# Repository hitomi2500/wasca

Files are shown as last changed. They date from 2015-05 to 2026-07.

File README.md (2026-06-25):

# wasca
wasca is a multipurpose Sega Saturn cartridge based on Lattice ECP5 FPGA with PicoRV32 RISC-V soft CPU core ([`picorv32`][2]). 

wasca can operate in several modes:

- Backup memory cartridge
- RAM expansion cartridge
- ROM cartridge
- Homebrew software compiled as a cartridge ROM 

> Netlink support is planned via an ESP32-CAM module connected to the 6-pin expansion header.

> Optical drive emulation (ODE) function is theoretically possible, but not planned currently.

> Profiling can be supported using a special firmware version, but it requires support from SH-2 code.

---

# Quick Start

1. Prepare the SD card formatted as FAT32. Other filesystems like NTFS and exFAT are not supported.
2. Copy `wasca.ss` and `wasca.rv` to the SD card root directory. Note that the file names should be in lowercase on the card, check FAT32 LFN support or reformat the card if they are not.
3. Insert the SD card into wasca, plug wasca into the cartridge slot, power on the console
4. Verify that the front LED on the cartridge turns red, then blue.
5. wasca menu should appear on screen after boot logo. Some ODEs can bypass wasca boot process entirely. In this case, consult your ODE documentation to learn how to return to cartridge boot mode after selecting a game.

---

# LED Status Reference

| Color | Meaning |
|---|---|
| Red | Reading SD card at startup or system error. |
| Red, blinking | Boot error, either `wasca.ss` and `wasca.rv` was not found on SD card, refer to on-screen error message. |
| Blue | Firmware found on SD card, boot successful, waiting for menu selection. |
| Green, blinking | Write access in RAM or Homebrew mode. |
| Magenta, blinking | Write access to backup memory in backup mode or filesystem write access. |
| Cyan, blinking | Massive write access to backup memory (happens during format) or filesystem read access. |
| Yellow, blinking | Preparing backup memory |
| White, blinking | Filesystem open, close, seek etc.|

---

# Backup Memory Support

wasca supports four backup memory sizes:

- 0.5 MB (official Sega Saturn size)
- 1 MB
- 2 MB
- 4 MB

If not already present, the following backup files are created automatically on the SD card when selected from the menu:

- `backup05.bin`
- `backup1.bin`
- `backup2.bin`
- `backup4.bin`

Syncronization is done automatically, led blinking with magenta color signals write access, led blinking with cyan signals massive write access and usually happens during cart format in BIOS.

---

# RAM Expansion Support

wasca supports these RAM expansion modes:

- 1 MB official RAM expansion (timings not 100% compatible)
- 4 MB official RAM expansion
- Heart of Darkness mode (HoD will work in homebrew mode as well)

---

# ROM Support

The following games require corresponding ROM files placed in the SD card root directory:

| Game | Required File |
|---|---|
| King of Fighters '95 | `kof95.bin` |
| Ultraman | `ultraman.bin` |

When present on SD card, ROM will appear in menu and should be selected prior to launching the game.

---

# Homebrew Support

Any Sega Saturn homebrew compiled for cartridge can be placed into the SD card root directory. `.ss` and `.bin` extensions are supported. wasca automatically scans and lists `.bin` and `.ss` files found in the SD card root directory.

In homebrew mode, wasca exposes:

- 32 MB of CS0 space
- 16 MB of CS1 space

These regions are available to the developer as RAM.

[`Yaul`][1] system library supports compiling sortware for cartridge with a special makefile include (build.post.ss.mk) that should be added to the project's Makefile instead of the default one (build.post.iso-cue.mk).

---

# Menu limit

Currently, wasca menu is limited to 18 items. If more `.bin` and `.ss` files that fit on screen are present in the SD card root, only first items will be shown. Use wasca commander (still under development) file manager to load extra files or files in non-root folders.

---

# Firmware update

wasca firmware consists of 3 parts:

- FPGA gateware: `attosoc.bit`
- RISC-V firmware: `wasca.rv`
- SH-2 firmware: `wasca.ss`

### Updating FPGA gateware

1. Disconnect wasca from the console
2. Remove two screws on the back of the cartridge
3. Open the cartridge shell
4. Connect wasca to PC using USB-C cable
5. A removable drive will appear
6. Copy `attosoc.bit` onto the drive
7. Wait for 2 minutes before disconnecting the cartridge
8. Assemble the cartridge and connect to the console.

### Updating RISC-V and SH-2 Firmware

1. Remove SD card from wasca
2. Replace the existing `wasca.rv` and `wasca.ss` files on the SD card with a newer version.
3. Re-insert the card. Console power cycle is necessary for wasca to load the new firmware.

---

# SD card removal
Removing the SD card when console is powered up is only recommended when the front LED is not lit and not blinking. Re-inserting the card without reset is possible if LED did not blink while the card was removed, but data integrity is not tested and not guaranteed.

---

# Troubleshooting

### Lit red LED and/or "wasca : boot error" on screen

Possible causes:
- Unsupported filesystem
- Bad SD card
- Unstable SD card connection

Try:
- Re-insert the SD card
- Reformat the SD card as FAT32
- Replace SD card

### Blinking red LED and/or missing file message on screen

Possible causes:
- Missing `wasca.ss` or `wasca.rv` in the SD card root
- Unsupported filesystem
- Bad SD card

Try:
- Verify that both `wasca.ss` and `wasca.rv` exists in the SD card root directory, named in lowercase
- Reformat the SD card as FAT32
- Replace the SD card

### Lit blue LED, wasca boot menu does not appear during boot

Possible causes:
- Poor cartridge connection
- Dirty cartridge connector
- ODE bypassing cartridge initialization

Try:
- Reseating the cartridge
- Cleaning the cartridge and connector
- Consulting your ODE documentation for cartridge boot instructions

### Game ROM of homebrew .ss file present in root folder, but does not appear in the menu

Possible causes:
- Too many files in SD card root
- Wrong charset

Try:
- Verify that there is enough place on the screen to print necessary menu item. If last menu item is 18, it's probably overfilled and extra items are not shown.
- Verify that the file extension is `.bin` or `.ss`, lowercase, latin1 characters.

[1]: https://github.com/ijacquez/libyaul
[2]: https://github.com/YosysHQ/picorv32

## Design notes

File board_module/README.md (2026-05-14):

This version of wasca board uses Muselab's Icesugar-pro board as a submodule.

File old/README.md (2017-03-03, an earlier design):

# wasca
Sega Saturn multipurpose cartridge, still in development phase. It will mimic Power Memory / Backup RAM, 1MB ROMs from KoF and Ultraman, and 1M/4M RAM expansion. More than that, it should emulate Sega Saturn modems, and launch any 3rd party code, for example PseudoSaturn.
Cart is based on Altera MAX 10 FPGA with external SDRAM and internal Nios II soft CPU. 
Development version is built around Zynq-based board named snickerdoodle.




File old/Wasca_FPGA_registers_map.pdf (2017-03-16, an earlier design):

## Wasca memory maps v. 0.4

This is a short document describing max10-based wasca cartridge memory and registers map from both SH-2 and in-FPGA Nios II soft cpu perspective. It also covers some aspects about developer Zynq-based board (this one is not named yet).
Part 1. SH-2 memory map
All the absolute addresses in this part of the document are in SH-2 cache-through address space unless otherwise specified.
Table 1-1 describes differencies between SH-2's chipselect spaces and A-bus (SMPC's chipselects). Further chipselect references will be using A-Bus ranges.
Address range | Size | SH-2 chipselects | A-Bus Chipselects | wasca usage
0x22000000 -0x23FFFFFF | 32 MB | CS0 | CS0 | Yes
0x24000000 -0x24FFFFFF | 16 MB | CS1 | CS1 | Yes
0x25000000 -0x257FFFFF | 8 MB | | Dummy | No
0x25800000 -0x258FFFFF | 1 MB | | CS2 | Not yet

Table 1-1. SH-2 and A-bus chipselect ranges.

Table 1-2 shows a detailed map of CS0 and CS1 and its usage by some official and unofficial carts.

Address range | Size | CS | Power memory | RAM cart | ROM cart | Bootable cart
0x22000000 - 0x221FFFFF | 2 M | CS0 | | | Data | Code and data
0x22200000 - 0x223FFFFF | 2 M
0x22400000 - 0x225FFFFF | 2 M | | | Lower data
0x22600000 - 0x227FFFFF | 2 M | | | Upper data
0x22800000 - 0x23FFFFFF | 24 M
0x24000000 – 0x24FEFFFF | 15.9999 M | CS1 | Data
0x24FFFFFC | 4 | | ID | ID | 0xFFFF | 0xFFFF

Table 1-2. Detailed CS0 and CS1 memory maps for various carts.

Table 1-3 shows the same map of CS0 and CS1 and its usage by wasca. Empty areas in tables 1-2 and 1-3 are unmapped, and should return unpredictable value (mostly 0xFFFF) on every read access. Write accesses in these areas are ignored.

Address range | Size | CS | wasca mode
| | | INIT | Power memory | RAM | <32M ROM | 32M ROM
x22000000 - 0x221FFFFF | 2 M | CS0 | Bootcode | | | ROM | ROM
0x22000000 - 0x223FFFFF | 2 M
0x22400000 - 0x225FFFFF | 2 M | | | | RAM
0x22600000 - 0x227FFFFF | 2 M
0x22800000 - 0x23FEFFFF | 23.94 M
0x23FF0000 - 0x23FFDFFF | 56K | | Reserved
0x23FFE000 - 0x23FFEFFF | 4K | | Filesystem interface
0x23FFF000 - 0x23FFFFFF | 4K | | wasca system area
0x24000000 - 0x24FE0FFF | 15.94 M | CS1 | | Power memory
0x24FF0000 - 0x24FFDFFF | 56K | | | | | | Reserved
0x24FFE000 - 0x24FFEFFF | 4K | | | | | | File system interface
0x24FFF000 - 0x24FFFFFB | 4092 | | | | | | wasca system area
0x24FFFFFC (ID) | 4 | | 0xFF | 0x2x | 0x5x | 0xFF | 0xFF
Table 1-3. Detailed CS0 and CS1 memory maps.

Filesystem interface is introduced to allow SH2 browse SD card or other media content, read, write or select files there. Selecting file is required for custom ROM operation mode. Filesystems registers are 16-bit-wide and should be accessed with 16-bit accesses and 16-bit address align. Other access sizes and/or unaligned addresses will lead to unpredictable behavior. Filesystem is locked after reset, and should be unlocked by writing 0xFADE inlo LOCK register. While locked, filesystem interface behaves as an unmapped area, LOCK register is write-only.

Offset | Size | R/W | Name | Description
0x000 | 2048 | R/W | DATA BUFFER | Buffer for storing data for write and read operations.
0x800 | 2032 | R/W | COMMAND BUFFER | Buffer for storing commands and replies. SH-2 software should write a valid command here before writing to bit 0 of the COMMAND register. Commands should be UTF8-encoded. When bit 0 in STATUS register reports a command completion, SH-2 should expect result here. Error messages requested by bit 1 in the command register appears here as well. SH-2 should not read this buffer while busy bit in STATUS register is active.
0xFF0 | 2 | R/W | LOCK | Write 0xFADE to this register to unlock filesystem functionality. Filesystem control is locked after every reset

| | | | and should be unlocked by SH2 software. Writing any other value into this register enables lock again.
0xFF2 | 1 | W | COMMAND | SH-2 software should write '1' to bit 0 to start a command stored in the command buffer beforehand. To get last error message, SH-2 software should write '1' to bit 1. Other bits are reserved, and should be written as zeros.
0xFF4 | 2 | R | STATUS | Bit 0 : busy bit, 1 when command is processed, 0 when done. Bit 1 : error bit, flags if any errors were detected during the last command. Other bits are reserved and should be ignored.

Table 1-4. Filesystem interface.

Filesystem interface support a reduced set of unix-shell-like commands. Please note that the command syntax and replies structure are not unix-shell compatible, do not use a man pages or other general documentation as a reference. Supported commands are enclosed in table 1-5. <0> are zero-terminators.
File and folder names could be either relative (e.g. “sound/sega.wav”), or absolute (e.g. “/sdcard/media/sound/sega.wav”). If no path provided for a filename, current folder is used.
Command | Syntax | Description
cd | cd <folder><0> | Enters a specified folder. If “..” is provided as a folder name, leaves current folder.
close | close <0> | Closes currently opened file.
cp | cp <filename 1> <filename 2><0> | Copies file1 to file2. If file2 exists, returns error and does nothing.
ls | ls<0> | Lists current folder. Filename are is stored in the COMMAND BUFFER, separated by zero-symbols. List is ended by double zero. Due to limited command buffer size, command could return an incomplete list, to get further files in the folder SH-2 software should issue ls command again. When the command returns a zero list (started by a two zero-symbols), there are no more files to list. Issuing any other command resets this one to the start of the folder.
mv | mv <filename 1> <filename 2><0> | Moves file1 to file2. If file2 exists, returns error and does nothing.
open | open <filename> [ <access>]<0> | Opens a file for reading or writing. Valid access fields are “r” (read-only, default), “w” (read-write), “n” (read-write, create file, truncate file if exists). If the file does not exist and the access field is not “n”, error is returned. Only 1 file can be opened at a time, issuing open when a file is already open closes currently open file.
pwd | pwd<0> | Returns current path
read | read <number><0> | Reads a number of bytes into DATA BUFFER. Returns error if number is more than 2048 or no file is currently opened.
rm | rm <filename><0> | Deletes a file from the filesystem. If file does not exist, returns error.
seek | seek <number><0> | Sets a data pointer in a file to the position provided by

| | number. Poiter is automatically set to 0 when opening file, and auto-increases when reading or writing, so seeking could be avoided when accessing file from the start to the end.
stat | stat <filename><0> | Returns a detailed file characteristics, like size, permissions, user, group etc. in the text format similar to 'ls -l' in linux.
write | write <number><0> | Writes a number of bytes from DATA BUFFER. Returns error if number is more than 2048 or no file is currently opened.

Table 1-5. Filesystem commands.

Table 1-6 describes wasca system area. System wasca registers are 16-bit-wide and should be accessed with 16-bit accesses and 16-bit address align. Other access sizes and/or unaligned addresses will lead to unpredictable behavior. Address range for system area is remapped in 32M ROM mode.

Offset | Size | R/W | Name | Description
0x000 | 4080 | | Reserved
0xFF0 | 2 | R | PCNTR | Wasca Prepare counter. Reset value is 0, after writing a valid value to MODE, this counter shows value (in percents) of the prepare progress. When this register has value of 0x0064, wasca is ready to emulate specified cart. Higher values should not appear normally.
0xFF2 | 2 | R | STATUS | Wasca Status register. Error and flag bits appears here. Bit 0 – SD card error when 1 Bit 1 – SDRAM test failed when 1 Bit 2 – USB transfer error when 1 Other bits are reserved
0xFF4 | 2 | R/W | MODE | wasca Mode Register Divided into 4 octets, non-zero octet selects cart type, octet value selects card subtype. See table 5 for additional description. Setting values not provided in table 5 results in unpredictable behavior.
0xFF6 | 2 | R | HWVER | wasca hardware version, major and minor 0x050C = v5.12
0xFF8 | 2 | R | SWVER | wasca embedded software version, major and minor (same format as HWVER) This register is zero at reset, and is written by cart's firmware right after boot. If by the time SH-2 is running the bootcode this value is still zero, it means cart failure. SH-2 cannot alter this register.
0xFFA | 6 | R | SIGNATURE | For max10 “wasca “ in ASCII (0x7761 0x7363 0x6120), for snickerdoodle “doodle” in ASCII (0x646F 0x6F64 0x6C5C). Signature unavailable in remapped (32M ROM) mode.

Table 1-5. Wasca system area registers.

Okay, and now the promised wasca modes table:

MODE value | Description
0x0000 | INIT
0x0001 | Power memory, 0.5 MB
0x0002 | Power memory, 1 MB
0x0003 | Power memory, 2 MB
0x0004 | Power memory, 4 MB
0x0020 | RAM expansion, 1 MB
0x0040 | RAM expansion, 4 MB
0x0100 | ROM, KoF95.bin
0x0200 | ROM, Ultraman.bin
0x0F00 | ROM, custom. Actual ROM file is selected via filesystem interface by SH-2. If the file size is 32M, wasca registers are remapped according to the table 1-3.
Other values | Unpredictable

Table 1-5. Valid wasca MODE register values.

Part 2. Nios II memory map
Nios II address range is FPGA-dependent (will be different for different FPGA parts) and is still work in progress, so it might change occasionally. Please check the last wasca FPGA project from repository for the valid memory map. Table 2-1 shows a memory map for Nios II soft cpu.
Address range | Size | Description
0x00000000 -0x0002AFFF | 172 KB | On-chip flash. It stores both Nios II software and SH-2 bootcode (compiled into Nios II software as binary).
0x00040000 — 0x0040001F | 32 B | UART registers
0x00041000 — 0x000417FF | 2 KB | Debug RAM
0x00042000 — 0x0004200F | 16 B | PLL setup
0x00043000 — 0x000433FF | 1 KB | SD card interface
0x00044000 — 0x0004400F | 16 B | Reserved
TBD | TBD | Filesystem interface
0x00045000 — 0x000451FF | 512 B | wasca system registers
0x00080000 — 0x000827FF | 10K | RAM

Table 2-1. Nios II memory map.

The scope of this document does not cover Nios II peripheral description, but it is well covered in Altera docs. The custom cores in Nios II memory map are filesystem interface and wasca system registers interface. Filesystem interface is TBD, wasca system area is shown in table 2-2.

Offset | Size | R/W | Name | Description
0x000 | 4080 | | Reserved
0xFF0 | 2 | R/W | PCNTR | Wasca Prepare counter. After sensing a non-zero value in MODE register Nios should start the prepare process, and write the progress periodically into this value (in percents).
0xFF2 | 2 | R/W | STATUS | Wasca Status register. Nios should write status here. See corresponding register in SH-2 memory map.
0xFF4 | 2 | R | MODE | wasca Mode Register Nios should scan this register while in INIT mode, and switch to corresponding mode when it changes. See corresponding register

| | | | in SH-2 memory map.
0xFF6 | 2 | R | HWVER | wasca hardware version, major and minor 0x050C = v5.12
0xFF8 | 2 | R/W | SWVER | This register is zero at reset, and is written by Nios soft CPU right after boot. See corresponding register in SH-2 memory map.
0xFFA | 6 | | Reserved

Table 2-2. wasca system area from Nios II perspective.

Part 3. Zynq memory map
Zynq memory map is generated automatically by Vivado. After this Vivado generates macros for every IP core, and the actual address is tied to that macros. Therefore, in the scope of this document, only the relative addresses (within IP core) will be described.

CORE 1: A-Bus bridge.
Accessible by AXI4Lite bus for status and configuration. Uses the same address map as Nios II (see table 2-2).

CORE 2: Filesystem interface.
Accessible by AXI4Lite bus for data transfer. Uses the same address map as Nios II (TBD).

CORE 3: Snoop core.
Accessible by AXI4Lite bus for status and configuration. Snoop core catches transactions over A-Bus and records them as a list into DDR.
Offset | Size | R/W | Name | Description
0x000 | 4 | R/W | SNOOP_ADDRESS | Selects address in an AXI space range for snooping A-BUS data transactions.
0x004 | 4 | R/W | SNOOP_FILTER | Filter for snooping only desired transactions. Set the corresponding bit to 1 to enable. Bit 0 – CS0, Bit 1 – CS1, Bit 2 – CS2, Bit 3 – reads, Bit 4 – writes.
0x008 | 4 | R/W | SNOOP_FORMAT | Snooping format as follows: 0x00 – 16 bit (1bit r/w, 15 bit lower address) 0x01 – 32 bit (1 bit r/w, 2 bit cs, 26 bit address, 3 bit hold length) 0x02 – 64 bit (1 bit r/w, 2 bit cs, 26 bit address, 16 bit data, 3 bit hold length, 1 bit hold ignore, 15 bit timestamp)
0x00C | 4 | R/W | SNOOP_CONTROL | Bit 0 enables and disables snoop. Bit 1 resets snoop to start address and clears itself.
0x010 | 4 | R | SNOOP_COUNTER | Holds value for current number of transactions snooped. Resets to 0 after setting bit 1 in SNOOP_CONTROL

CORE 4: Display core.
Accessible by AXI4Lite bus for data transfer. Display sports its own internal video buffer, so the data in the core's memory is not displayed upon writing, but should be uploaded from core into display first. To do this one should either upload data manually by writing 1 to
DISPLAY_CONTROL register, or enable auto-upload.
Offset | Size | R/W | Name | Description
0x00000 | 0x12C00 | R/W | FRAMEBUFFER | Framebuffer for holding pixel data.
0x1F000 | 1 | R/W | DISPLAY_CONTROL | Bit 0 – uploads framebuffer upon writing 1 Bit 1 – enables automatic upload

0x1F004 | 1 | R | UPLOAD_STATUS | Bit 0 – upload is active.
0x1F008 | 4 | R/W | UPLOAD_INTERVAL | Automatic upload interval in microseconds.
0x1F00C | 4 | R | UPLOAD_COUNTER | This counter cyclically counts from 0 to UPLOAD INTERVAL, then resets to 0 and starts over. Upload occurs when UPLOAD_COUNTER is 0. Upload takes some time, software should check UPLOAD_STATUS register before writing to buffer.
0x1F010 | 1 | R/W | BACKLIGHT | Backlight intensity. 0x00 – minimal, 0xFF -maximal.

Part 4. Revision history

v0.1 | Preliminary version, system regs and SD card interface, only SH-2 perspective
v0.2 | Nios perspective added, some additional comments
v0.3 | SD card interface removed, filesystem interface added, Zynq perspective added
v0.4 | Filesystem interface changed drastically

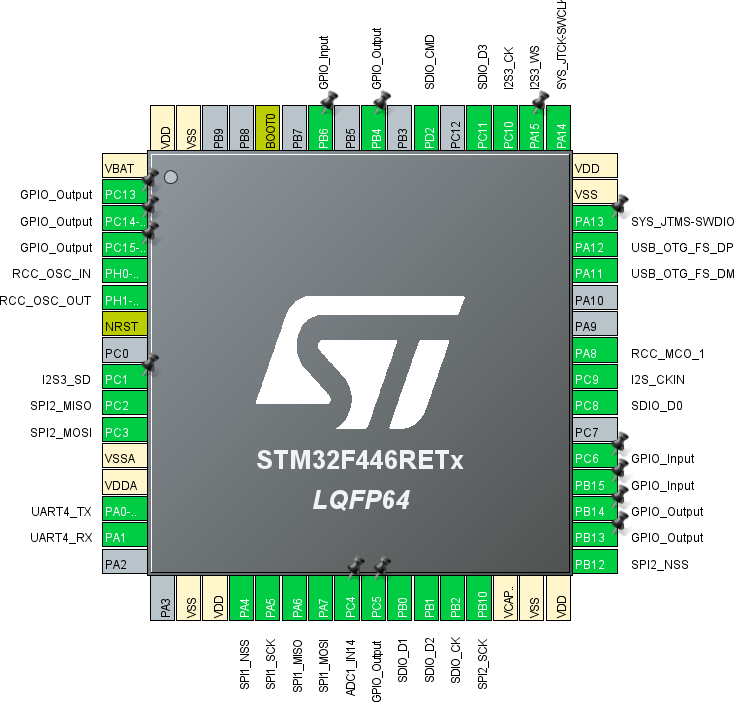
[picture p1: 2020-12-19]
board_module/STM32_pinout.png

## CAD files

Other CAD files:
fpga_firmware/wasca_signaltap.stp

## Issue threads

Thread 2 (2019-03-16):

SDRAM access timing adjustement in firmware v1.x

cafe-alpha, 2019-03-16:
Long time no see ! Pseudo Saturn Kai development reached a milestone big enough so that I can finally put more time on Wasca development.

And, as indicated in the title, I'm currently experiencing SDRAM access issues in firmware v1.x (MAX 10-based) from a design to another, which improves by randomly changing settings in Qsys and heavy prayings ... in simpler words, I'm flooded with technical difficulty of firmware development.

So I would like to know how you managed to adjust access timing for SDRAM in v1.0 board (which was running Saturn test utility from emulated boot ROM, hence with working SDRAM access) : from my limited understanding, as this requires to dedicate one clock signal for SDRAM chip (and adjust its phase with slack from address/data signals), I was thinking to use second clock output from MAX10's PLL as clock signal for SDRAM.
But firmware v1.0/v1.1 uses only one clock output from PLL, so if there's another way to adjust SDRAM access timing, please inform me about it.

I suppose you still prefer the snickerdoodle-based architecture, but that would be really appreciated if you want to give an hand on MAX 10 one ♪

hitomi2500, 2020-08-17:
Just thought about commenting on this one. I actually never fine-tuned any hard timings or pin delays, it worked magically as it was. Yes, there was some qsys config involved, but it was only about CAS latency and other timings from datasheet. Basically, it's the second page of the sdram controller setup.
As far as i understand, the sdram controller expects its clock to be the same as memory IC clock, and it does the data-to-clock phase alignement (basically just latching with a negative clock edge at the i/o) itself.

cafe-alpha, 2020-08-18:
Thank you for the reply. I honestly don't remember in detail which kind of problem I had at the moment I wrote this issue, but it was either me having troubles to read the datasheet or incorrectly soldering things on the PCB ? Or maybe it was more likely to occur when SPI component was added ?
Now, I no longer have such kind of problem, but it's also a long time I didn't tested on my own board. I can't wait to try your design on it !

hitomi2500, 2021-02-05:
I suppose i will close this one.

Closed 2021-02-05.

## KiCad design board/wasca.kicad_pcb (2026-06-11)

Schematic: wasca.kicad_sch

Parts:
C1, C2, C4, C5, C7, C9, C10, C11, C14, C15, C16, C17, C18, C19, C20, C21, C22, C23, C24, C25, C26, C27, C28, C33, C34, C35, C36, C37, C38, C39, C40, C46, C47, C48: 0.1uF; C_0603_1608Metric_Pad1.08x0.95mm_HandSolder; LCSC C1590
C3, C6, C8, C29: 4.7uF; C_0603_1608Metric_Pad1.08x0.95mm_HandSolder; LCSC C1705
C12, C13: 15pF; C_0603_1608Metric_Pad1.08x0.95mm_HandSolder; LCSC C1644
C30, C31: 22uF; C_0603_1608Metric_Pad1.08x0.95mm_HandSolder; LCSC C59461
C32, C41: 1uF; C_0603_1608Metric_Pad1.08x0.95mm_HandSolder; LCSC C1592
C42, C43: 18pF; C_0603_1608Metric_Pad1.08x0.95mm_HandSolder; LCSC C1647
C44, C45: 10uF; C_1206_3216Metric_Pad1.33x1.80mm_HandSolder; LCSC C1691
C49, C50, C51, C52, C53, C54, C55, C56, C57, C58, C59: 0.1uF; C_0402_1005Metric; LCSC C1525
CN1: UC09-0B16F00P11; DX07S016JA1R1500; LCSC C36936538
CN2: CARTRIDGE_EDGE_CONNECTOR; CARTRIDGE_EDGE_CONNECTOR2; not fitted
CN3: TFP09-2-12B; TFP09212B; Manufacturer_Part_Number TFP09-2-12B; not fitted
CN4: SD-CARD 11P; 693063020911; PART-NUMBER 693063020911; LCSC C7529393
CN5: 2.54-1*8P母环保; MODULE_ESP32-CAM-HALF; LCSC C27438
D1: BAT54C; SOT-23; LCSC C2135
D2: LED_RGB; LED_RGB_5050-6; not fitted
D3: LED_BKGR; LED_D5.0mm-4_RGB; LCSC C7371892
D4: LED; LED_0805; LCSC C965863
KICAD1: KICAD_LOGO; DESIGNED_WITH_KICAD_10X05; not fitted
L1, L2: 2.2uH; L_1008_2520Metric; LCSC C86092
R1, R4: 5.1K; R_0603_1608Metric_Pad0.98x0.95mm_HandSolder; LCSC C23186
R2, R19, R20: 1K; R_0603_1608Metric_Pad0.98x0.95mm_HandSolder; LCSC C21190
R3, R7, R8, R16, R17, R28: 0; R_0603_1608Metric_Pad0.98x0.95mm_HandSolder; LCSC C21189
R5, R6: 27; R_0603_1608Metric_Pad0.98x0.95mm_HandSolder; LCSC C25190
R9: 680K; R_0603_1608Metric_Pad0.98x0.95mm_HandSolder; LCSC C2907061
R10: 200K; R_0603_1608Metric_Pad0.98x0.95mm_HandSolder; LCSC C25811
R11, R14, R15: 470; R_0603_1608Metric_Pad0.98x0.95mm_HandSolder; LCSC C23179
R12: 150K; R_0603_1608Metric_Pad0.98x0.95mm_HandSolder; LCSC C22807
R13: 240K; R_0603_1608Metric_Pad0.98x0.95mm_HandSolder; LCSC C4197
R18, R35: 4K7; R_0603_1608Metric_Pad0.98x0.95mm_HandSolder; LCSC C23162
R21, R22, R29, R30, R31, R32, R33, R34, R36: 10K; R_0603_1608Metric_Pad0.98x0.95mm_HandSolder; LCSC C15401
R23, R24, R25, R26, R27: 33K; R_0603_1608Metric_Pad0.98x0.95mm_HandSolder; LCSC C4216
SEGATA1: LOGO; Segata_Sanshiro; not fitted
SHIRO!1: SHIRO_LOGO; SHIRO!; not fitted
SW1, SW2: TS-1101-C-W; SW_Tactile_SPST_NO_Straight_CK_PTS636Sx25SMTRLFS; LCSC C318938
TP1: TestPoint; TestPoint_Pad_D1.5mm; not fitted
TP2: 5VSAT; TestPoint_Pad_D1.5mm; not fitted
TP3: 5VSYS; TestPoint_Pad_D1.5mm; not fitted
TP4: 5VUSB; TestPoint_Pad_D1.5mm; not fitted
TP5: 2.5V; TestPoint_Pad_D1.5mm; not fitted
TP6: 3.3V; TestPoint_Pad_D1.5mm; not fitted
TP7: 1.1V; TestPoint_Pad_D1.5mm; not fitted
TP8: DONE; TestPoint_Pad_D1.0mm; not fitted
TP9: TCK; TestPoint_Pad_D1.0mm; not fitted
TP10: TDI; TestPoint_Pad_D1.0mm; not fitted
TP11: TMS; TestPoint_Pad_D1.0mm; not fitted
TP12: TDO; TestPoint_Pad_D1.0mm; not fitted
TP13, TP14: TestPoint; TestPoint_Pad_D1.0mm; not fitted
U1, U2, U4, U5, U6: SN74LVC1T45DBVR; SOT-23-6; LCSC C7843
U3, U17: P25Q16SH-SSH-IR; SOIC-8_5.3x5.3mm_P1.27mm; LCSC C7466814
U7, U8, U10: 74ALVC164245DGG:11-JSM; TSSOP-48_6.1x12.5mm_P0.5mm; LCSC C53436298
U9: RP2040; QFN-56-1EP_7x7mm_P0.4mm_EP3.2x3.2mm; LCSC C2040
U11, U12: W9825G6KH-6; TSOP-II-54_22.2x10.16mm_P0.8mm; LCSC C62246
U13, U14: SY8008CAAC; SOT23-5_SY8008B_SGY; LCSC C81889
U15: XC6206P252MR; SOT-23-3; LCSC C15906
U16: LFE5U-25F-6BG256I; caBGA256_LAT; LCSC C1521614
VACHE1: LOGO; LOGO_VACHE_SIM; not fitted
Y1: X322512MSB4SI; Crystal_SMD_3225-4Pin_3.2x2.5mm; LCSC C9002
Y2: SX2M25.000M20F30TNN; Oscillator_SMD_SeikoEpson_SG210-4Pin_2.5x2.0mm_HandSoldering; LCSC C2901601

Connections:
/5V_SATURN_DETECT: R35.2, R36.1, U16.J13 (PR17C)
/+1_1V: C54.1, C56.1, C58.1, R17.2, U16.G6 (VCC), U16.G7 (VCC), U16.G9 (VCC), U16.L8 (VCC), U16.L9 (VCC), U16.L10 (VCC)
/+1_1V_RPI: C22.1, C24.1, C26.1, TP1.1 (1_1), U9.23 (DVDD), U9.45 (VREG_VOUT), U9.50 (DVDD)
/+2_5V: C49.1, C50.1, R8.2, U16.G11 (VCCAUX), U16.L7 (VCCAUX)
/+3_3V: C4.1, C5.1, C7.1, C17.1, C18.1, C19.1, C20.1, C21.1, C23.1, C25.1, C27.1, C28.1, C33.1, C34.1, C35.1, C36.1, C37.1, C38.1, C39.1, C40.1, C46.1, C48.1, C51.1, C52.1, C53.1, C55.1, C57.1, C59.1, CN3.4 (VDD), CN4.4 (VDD), R7.2, R16.2, R19.2, R21.1, R22.1, R23.1, R24.1, R25.1, R26.1, R27.1, R28.1, R29.1, R30.1, R31.1, R32.1, R33.1, R34.1, U1.1 (VCCA), U2.1 (VCCA), U3.8 (VCC), U4.1 (VCCA), U4.5 (DIR), U5.1 (VCCA), U5.5 (DIR), U6.1 (VCCA), U6.5 (DIR), U7.31 (VCCA), U7.42 (VCCA), U8.31 (VCCA), U8.42 (VCCA), U9.1 (IOVDD), U9.10 (IOVDD), U9.22 (IOVDD), U9.33 (IOVDD), U9.42 (IOVDD), U9.44 (VREG_VIN), U9.48 (USB_VDD), U9.49 (IOVDD), U10.31 (VCCA), U10.42 (VCCA), U11.1 (VDD), U11.3 (VDDQ), U11.9 (VDDQ), U11.14 (VDD), U11.27 (VDD), U11.43 (VDDQ), U11.49 (VDDQ), U12.1 (VDD), U12.3 (VDDQ), U12.9 (VDDQ), U12.14 (VDD), U12.27 (VDD), U12.43 (VDDQ), U12.49 (VDDQ), U16.F6 (VCCIO0), U16.F7 (VCCIO0), U16.F10 (VCCIO1), U16.F11 (VCCIO1), U16.H6 (VCCIO7), U16.H7 (VCCIO7), U16.H11 (VCCIO2), U16.J6 (VCCIO6), U16.J7 (VCCIO6), U16.J11 (VCCIO2), U16.K11 (VCCIO3), U16.L6 (VCCIO8), U16.L11 (VCCIO3), U16.P10 (CFG_1), U17.8 (VCC), Y2.4 (Vcc)
/+5V_SATURN: C1.1, C2.1, C3.1, C8.1, C9.1, C10.1, C11.1, C14.1, C15.1, C16.1, CN2.A1 (VCC), CN2.A2 (VCC), CN2.A27 (VCC), CN2.A67 (VCC), CN2.B1 (VCC), CN2.B2 (VCC), CN2.B27 (VCC), CN2.B67 (VCC), D1.1, R35.1, TP2.1 (1_1), U1.6 (VCCB), U2.6 (VCCB), U4.6 (VCCB), U5.6 (VCCB), U6.6 (VCCB), U7.7 (VCCB), U7.18 (VCCB), U8.7 (VCCB), U8.18 (VCCB), U10.7 (VCCB), U10.18 (VCCB)
/+5V_SYS: C29.1, C30.1, C31.1, C32.1, C47.1, CN5.1 (5V), D1.3, TP3.1 (1_1), U13.1 (EN), U13.4 (IN), U14.1 (EN), U14.4 (IN), U15.3 (VI)
/+5V_USB: C6.1, CN1.A4 (VBUS), CN1.A9 (VBUS), CN1.B4 (VBUS), CN1.B9 (VBUS), D1.2, TP4.1 (1_1)
/ABUS_3V_A1: U10.43 (1A3), U16.J14 (PR20C)
/ABUS_3V_A2: U7.30 (2A4), U16.T6 (PB4A)
/ABUS_3V_A3: U7.32 (2A3), U16.P5 (PL47D)
/ABUS_3V_A4: U7.33 (2A2), U16.R5 (PL44A)
/ABUS_3V_A5: U7.35 (2A1), U16.T4 (PL44B)
/ABUS_3V_A6: U7.36 (2A0), U16.R4 (PL41C)
/ABUS_3V_A7: U7.37 (1A7), U16.T3 (PL41D)
/ABUS_3V_A8: U10.37 (1A7), U16.N13 (PR38A)
/ABUS_3V_A9: U10.38 (1A6), U16.L13 (PR29C)
/ABUS_3V_A10: U10.41 (1A4), U16.K14 (PR20D)
/ABUS_3V_A11: U10.40 (1A5), U16.L14 (PR32C)
/ABUS_3V_A12: U10.35 (2A1), U16.P11 (PR47C)
/ABUS_3V_A13: U10.36 (2A0), U16.N12 (PR44D)
/ABUS_3V_A14: U7.38 (1A6), U16.R3 (PL41B)
/ABUS_3V_A15: U10.33 (2A2), U16.N6 (PL47B)
/ABUS_3V_A16: U7.40 (1A5), U16.T2 (PL38D)
/ABUS_3V_A17: U10.32 (2A3), U16.N5 (PL44D)
/ABUS_3V_A18: U7.41 (1A4), U16.P3 (PL38B)
/ABUS_3V_A19: U10.30 (2A4), U16.P4 (PL41A)
/ABUS_3V_A20: U7.43 (1A3), U16.R2 (PL38C)
/ABUS_3V_A21: U10.29 (2A5), U16.N4 (PL38A)
/ABUS_3V_A22: U7.44 (1A2), U16.R1 (PL35B)
/ABUS_3V_A23: U10.27 (2A6), U16.M4 (PL35C)
/ABUS_3V_A24: U7.46 (1A1), U16.P2 (PL32B)
/ABUS_3V_CS0: U10.44 (1A2), U16.H14 (PR14D)
/ABUS_3V_CS1: U7.27 (2A6), U16.R7 (PB6A)
/ABUS_3V_CS2: U10.46 (1A1), U16.G14 (PR14C)
/ABUS_3V_D0: U8.47 (1A0), U16.E13 (PT62B)
/ABUS_3V_D1: U8.46 (1A1), U16.D14 (PR2D)
/ABUS_3V_D2: U8.44 (1A2), U16.C13 (PT60B)
/ABUS_3V_D3: U8.43 (1A3), U16.R12 (PR44A)
/ABUS_3V_D4: U8.32 (2A3), U16.R15 (PR38C)
/ABUS_3V_D5: U8.33 (2A2), U16.T15 (PR38D)
/ABUS_3V_D6: U8.35 (2A1), U16.R14 (PR41B)
/ABUS_3V_D7: U8.36 (2A0), U16.T14 (PR41D)
/ABUS_3V_D8: U8.41 (1A4), U16.P12 (PR47D)
/ABUS_3V_D9: U8.40 (1A5), U16.R13 (PR41C)
/ABUS_3V_D10: U8.38 (1A6), U16.T13 (PR44B)
/ABUS_3V_D11: U8.37 (1A7), U16.P13 (PR41A)
/ABUS_3V_D12: U8.26 (2A7), U16.P16 (PR35A)
/ABUS_3V_D13: U8.27 (2A6), U16.P15 (PR32B)
/ABUS_3V_D14: U8.29 (2A5), U16.R16 (PR35B)
/ABUS_3V_D15: U8.30 (2A4), U16.P14 (PR38B)
/ABUS_3V_IRQ: U1.3 (A), U16.J3 (PL20C)
/ABUS_3V_MUX_DATA_DIR: U8.1 (1DIR), U8.24 (2DIR), U16.H4 (PL17B)
/ABUS_3V_RD: U7.29 (2A5), U16.R6 (PB4B)
/ABUS_3V_WR0: U10.47 (1A0), U16.F14 (PR5D)
/ABUS_3V_WR1: U7.26 (2A7), U16.R8 (PB13A)
/ABUS_A1: CN2.A45 (AA1), U10.6 (1B3)
/ABUS_A2: CN2.B44 (AA2), U7.19 (2B4)
/ABUS_A3: CN2.B43 (AA3), U7.17 (2B3)
/ABUS_A4: CN2.B42 (AA4), U7.16 (2B2)
/ABUS_A5: CN2.B40 (AA5), U7.14 (2B1)
/ABUS_A6: CN2.B39 (AA6), U7.13 (2B0)
/ABUS_A7: CN2.B38 (AA7), U7.12 (1B7)
/ABUS_A8: CN2.A40 (AA8), U10.12 (1B7)
/ABUS_A9: CN2.A42 (AA9), U10.11 (1B6)
/ABUS_A10: CN2.A44 (AA10), U10.8 (1B4)
/ABUS_A11: CN2.A43 (AA11), U10.9 (1B5)
/ABUS_A12: CN2.A38 (AA12), U10.14 (2B1)
/ABUS_A13: CN2.A39 (AA13), U10.13 (2B0)
/ABUS_A14: CN2.B37 (AA14), U7.11 (1B6)
/ABUS_A15: CN2.A37 (AA15), U10.16 (2B2)
/ABUS_A16: CN2.B35 (AA16), U7.9 (1B5)
/ABUS_A17: CN2.A35 (AA17), U10.17 (2B3)
/ABUS_A18: CN2.B34 (AA18), U7.8 (1B4)
/ABUS_A19: CN2.A34 (AA19), U10.19 (2B4)
/ABUS_A20: CN2.B33 (AA20), U7.6 (1B3)
/ABUS_A21: CN2.A33 (AA21), U10.20 (2B5)
/ABUS_A22: CN2.B32 (AA22), U7.5 (1B2)
/ABUS_A23: CN2.A32 (AA23), U10.22 (2B6)
/ABUS_A24: CN2.B31 (AA24), U7.3 (1B1)
/ABUS_CS0: CN2.A47 (ACS0), U10.5 (1B2)
/ABUS_CS1: CN2.B48 (ACS1), U7.22 (2B6)
/ABUS_CS2: CN2.A48 (ACS2), U10.3 (1B1)
/ABUS_D0: CN2.A55 (AD0), U8.2 (1B0)
/ABUS_D1: CN2.A56 (AD1), U8.3 (1B1)
/ABUS_D2: CN2.A57 (AD2), U8.5 (1B2)
/ABUS_D3: CN2.A58 (AD3), U8.6 (1B3)
/ABUS_D4: CN2.B58 (AD4), U8.17 (2B3)
/ABUS_D5: CN2.B57 (AD5), U8.16 (2B2)
/ABUS_D6: CN2.B56 (AD6), U8.14 (2B1)
/ABUS_D7: CN2.B55 (AD7), U8.13 (2B0)
/ABUS_D8: CN2.A60 (AD8), U8.8 (1B4)
/ABUS_D9: CN2.A61 (AD9), U8.9 (1B5)
/ABUS_D10: CN2.A62 (AD10), U8.11 (1B6)
/ABUS_D11: CN2.A63 (AD11), U8.12 (1B7)
/ABUS_D12: CN2.B63 (AD12), U8.23 (2B7)
/ABUS_D13: CN2.B62 (AD13), U8.22 (2B6)
/ABUS_D14: CN2.B61 (AD14), U8.20 (2B5)
/ABUS_D15: CN2.B60 (AD15), U8.19 (2B4)
/ABUS_IRQ: CN2.B53 (AIRQ), U1.4 (B)
/ABUS_RD: CN2.B47 (ARD), U7.20 (2B5)
/ABUS_WR0: CN2.A49 (AWR0), U10.2 (1B0)
/ABUS_WR1: CN2.B49 (AWR1), U7.23 (2B7)
/BUFFERS_OE: U7.25 (2OE), U7.48 (1OE), U8.25 (2OE), U8.48 (1OE), U10.25 (2OE), U10.48 (1OE), U16.L3 (PL32C)
/CLK_25M: U16.P6 (PL47C), Y2.3 (OUT)
/ESP32_CS: CN5.5 (IO15), U16.C6 (PT22A)
/ESP32_MISO: CN5.3 (IO12), U16.E7 (PT24A)
/ESP32_MOSI: CN5.4 (IO13), U16.D6 (PT20B)
/ESP32_SCK: CN5.6 (IO14), U16.C7 (PT27A)
/FPGA_QSPI_CLK: R30.2, U9.5 (GPIO3), U16.N9 (CCLK), U17.6 (CLK)
/FPGA_QSPI_CS: R29.2, U9.9 (GPIO7), U16.N8 (PB15A), U17.1 (~CS)
/FPGA_QSPI_D0: R31.2, U9.7 (GPIO5), U16.T8 (PB11B), U17.5 (DI/IO_{0})
/FPGA_QSPI_D1: R32.2, U9.12 (GPIO9), U16.T7 (PB11A), U17.2 (DO/IO_{1})
/FPGA_QSPI_D2: R33.2, U9.14 (GPIO11), U16.M7 (PB9B), U17.3 (~WP/IO_{2})
/FPGA_QSPI_D3: R34.2, U9.3 (GPIO1), U16.N7 (PB9A), U17.7 (~HOLD/~RESET/IO_{3})
/IBCK: CN2.A5 (IBCK), U5.4 (B)
/IBCK_3V: U5.3 (A), U16.F4 (PL8C)
/ILRCK: CN2.A6 (ILRCK), U6.4 (B)
/ILRCK_3V: U6.3 (A), U16.P8 (PB13B)
/IRQ_OUT_ENABLE: U1.5 (DIR), U16.F3 (PL5D)
/ISD: CN2.A4 (ISD), U4.4 (B)
/ISD_3V: U4.3 (A), U16.E3 (PL5C)
/JTAG_TCK: R18.2, TP9.1 (1_1), U16.T10 (TCK)
/JTAG_TDI: TP10.1 (1_1), U16.R11 (TDI)
/JTAG_TDO: TP12.1 (1_1), U16.M10 (TDO)
/JTAG_TMS: TP11.1 (1_1), U16.T11 (TMS)
/LEDB: R15.1, U16.D7 (PT24B)
/LEDG: R14.1, U16.E8 (PT33A)
/LEDR: R11.1, U16.E9 (PT40B)
/PROGRAMN: R21.2, SW2.2, U9.29 (GPIO18), U16.R9 (PROGRAMN)
/RESET: CN2.A3 (SYSRES), U10.23 (2B7)
/RESET_3V: U10.26 (2A7), U16.K4 (PL29A)
/RP_QSPI_CLK: U3.6 (CLK), U9.52 (QSPI_SCLK)
/RP_QSPI_CS: R2.2, U3.1 (~CS), U9.56 (~QSPI_SS)
/RP_QSPI_D0: U3.5 (DI/IO_{0}), U9.53 (QSPI_SD0)
/RP_QSPI_D1: U3.2 (DO/IO_{1}), U9.55 (QSPI_SD1)
/RP_QSPI_D2: U3.3 (~WP/IO_{2}), U9.54 (QSPI_SD2)
/RP_QSPI_D3: U3.7 (~HOLD/~RESET/IO_{3}), U9.51 (QSPI_SD3)
/SCSPCLK: CN2.A7 (SCSPCLK), U7.2 (1B0)
/SCSPCLK_3V: U7.47 (1A0), U16.G3 (PL14C)
/SDRAM1_A0: U11.23 (A0), U16.B8 (PT35B)
/SDRAM1_A1: U11.24 (A1), U16.A9 (PT42A)
/SDRAM1_A2: U11.25 (A2), U16.B9 (PT38A)
/SDRAM1_A3: U11.26 (A3), U16.A10 (PT42B)
/SDRAM1_A4: U11.29 (A4), U16.J16 (PR23A)
/SDRAM1_A5: U11.30 (A5), U16.K15 (PR23D)
/SDRAM1_A6: U11.31 (A6), U16.K16 (PR23C)
/SDRAM1_A7: U11.32 (A7), U16.L15 (PR26B)
/SDRAM1_A8: U11.33 (A8), U16.L16 (PR26A)
/SDRAM1_A9: U11.34 (A9), U16.M14 (PR32D)
/SDRAM1_A10: U11.22 (A10), U16.B10 (PT44A)
/SDRAM1_A11: U11.35 (A11), U16.M16 (PR26C)
/SDRAM1_A12: U11.36 (A12), U16.M15 (PR26D)
/SDRAM1_BA0: U11.20 (BA0), U16.B11 (PT49A)
/SDRAM1_BA1: U11.21 (BA1), U16.A11 (PT53A)
/SDRAM1_CAS: U11.17 (~CAS), U16.A13 (PT65A)
/SDRAM1_CKE: U11.37 (CKE), U16.N16 (PR32A)
/SDRAM1_CLK: U11.38 (CLK), U16.N14 (PR35D)
/SDRAM1_CS: U11.19 (~CS), U16.A12 (PT53B)
/SDRAM1_DQ0: U11.2 (DQ0), U16.E14 (PR5C)
/SDRAM1_DQ1: U11.4 (DQ1), U16.C16 (PR5A)
/SDRAM1_DQ2: U11.5 (DQ2), U16.C15 (PR5B)
/SDRAM1_DQ3: U11.7 (DQ3), U16.B16 (PR2A)
/SDRAM1_DQ4: U11.8 (DQ4), U16.B15 (PR2B)
/SDRAM1_DQ5: U11.10 (DQ5), U16.C14 (PR2C)
/SDRAM1_DQ6: U11.11 (DQ6), U16.A15 (PT67B)
/SDRAM1_DQ7: U11.13 (DQ7), U16.B14 (PT67A)
/SDRAM1_DQ8: U11.42 (DQ8), U16.H15 (PR20B)
/SDRAM1_DQ9: U11.44 (DQ9), U16.G16 (PR20A)
/SDRAM1_DQ10: U11.45 (DQ10), U16.G15 (PR14B)
/SDRAM1_DQ11: U11.47 (DQ11), U16.F16 (PR14A)
/SDRAM1_DQ12: U11.48 (DQ12), U16.F15 (PR11C)
/SDRAM1_DQ13: U11.50 (DQ13), U16.E16 (PR11D)
/SDRAM1_DQ14: U11.51 (DQ14), U16.E15 (PR8B)
/SDRAM1_DQ15: U11.53 (DQ15), U16.D16 (PR8A)
/SDRAM1_DQM0: U11.15 (DQML), U16.A14 (PT65B)
/SDRAM1_DQM1: U11.39 (DQMH), U16.J15 (PR23B)
/SDRAM1_RAS: U11.18 (~RAS), U16.B12 (PT56A)
/SDRAM1_WE: U11.16 (~WE), U16.B13 (PT60A)
/SDRAM2_A0: U12.23 (A0), U16.K1 (PL23C)
/SDRAM2_A1: U12.24 (A1), U16.J2 (PL23B)
/SDRAM2_A2: U12.25 (A2), U16.J1 (PL23A)
/SDRAM2_A3: U12.26 (A3), U16.H2 (PL20B)
/SDRAM2_A4: U12.29 (A4), U16.B6 (PT22B)
/SDRAM2_A5: U12.30 (A5), U16.A7 (PT29A)
/SDRAM2_A6: U12.31 (A6), U16.B7 (PT27B)
/SDRAM2_A7: U12.32 (A7), U16.A8 (PT29B)
/SDRAM2_A8: U12.33 (A8), U16.A6 (PT18B)
/SDRAM2_A9: U12.34 (A9), U16.B5 (PT15B)
/SDRAM2_A10: U12.22 (A10), U16.K2 (PL23D)
/SDRAM2_A11: U12.35 (A11), U16.A5 (PT18A)
/SDRAM2_A12: U12.36 (A12), U16.C5 (PT15A)
/SDRAM2_BA0: U12.20 (BA0), U16.L2 (PL26B)
/SDRAM2_BA1: U12.21 (BA1), U16.L1 (PL26A)
/SDRAM2_CAS: U12.17 (~CAS), U16.N1 (PL32A)
/SDRAM2_CKE: U12.37 (CKE), U16.A4 (PT6B)
/SDRAM2_CLK: U12.38 (CLK), U16.B4 (PT11B)
/SDRAM2_CS: U12.19 (~CS), U16.M1 (PL26C)
/SDRAM2_DQ0: U12.2 (DQ0), U16.D1 (PL8A)
/SDRAM2_DQ1: U12.4 (DQ1), U16.D3 (PL2D)
/SDRAM2_DQ2: U12.5 (DQ2), U16.E1 (PL11D)
/SDRAM2_DQ3: U12.7 (DQ3), U16.E2 (PL8B)
/SDRAM2_DQ4: U12.8 (DQ4), U16.F1 (PL14A)
/SDRAM2_DQ5: U12.10 (DQ5), U16.F2 (PL11C)
/SDRAM2_DQ6: U12.11 (DQ6), U16.G1 (PL20A)
/SDRAM2_DQ7: U12.13 (DQ7), U16.G2 (PL14B)
/SDRAM2_DQ8: U12.42 (DQ8), U16.C4 (PT11A)
/SDRAM2_DQ9: U12.44 (DQ9), U16.A2 (PT4A)
/SDRAM2_DQ10: U12.45 (DQ10), U16.B3 (PT4B)
/SDRAM2_DQ11: U12.47 (DQ11), U16.B2 (PL2B)
/SDRAM2_DQ12: U12.48 (DQ12), U16.B1 (PL2A)
/SDRAM2_DQ13: U12.50 (DQ13), U16.C3 (PL2C)
/SDRAM2_DQ14: U12.51 (DQ14), U16.C1 (PL5A)
/SDRAM2_DQ15: U12.53 (DQ15), U16.C2 (PL5B)
/SDRAM2_DQM0: U12.15 (DQML), U16.P1 (PL35A)
/SDRAM2_DQM1: U12.39 (DQMH), U16.A3 (PT6A)
/SDRAM2_RAS: U12.18 (~RAS), U16.M2 (PL26D)
/SDRAM2_WE: U12.16 (~WE), U16.N3 (PL35D)
/SD_CLK: CN3.5 (CLK), CN4.5 (CLK), U16.E11 (PT51B)
/SD_CMD: CN3.3 (CMD), CN4.2 (CMD), R25.2, U16.C9 (PT38B)
/SD_DAT0: CN3.7 (DAT0), CN4.7 (DAT0), R24.2, U16.C11 (PT49B)
/SD_DAT1: CN3.8 (DAT1), CN4.8 (DAT1), R23.2, U16.D12 (PT58A)
/SD_DAT2: CN3.1 (DAT2), CN4.9 (DAT2), R27.2, U16.D8 (PT33B)
/SD_DAT3: CN3.2 (DAT3/CD), CN4.1 (CD/DAT3), R26.2, U16.D10 (PT47A)
/SD_DET_A: CN3.10 (GND), CN4.CD, U16.C12 (PT56B)
/SD_DET_B: CN3.9 (CARD_DETECTION), U16.E10 (PT47B)
/SSEL: CN2.B3 (SSEL), U2.4 (B)
/SSEL_3V: R3.1, U16.D4 (PT9B)
/USB_DM: CN1.A7 (D-), CN1.B7 (D-), R5.1
/USB_DP: CN1.A6 (D+), CN1.B6 (D+), R6.1
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

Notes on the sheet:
--- Changelog --- V1.0 hitomi2500 : - Initial version with 10M04SFE, SDRAM, FT201XS V1.1 hitomi2500 : - Both DDR/SDRAM support - Added USB and bluetooth support - Sound I/O mapped to MAX10 V1.2 cafe-alpha : - Changed PCB shape and ICs position in order to fit Action Replay case - Changed MAX10 chip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
PROGRAM PICO
Compatible connectors: Hroparts TF-01A SOFNG TF-15x15 SOFNG TF-015 XUNPU TF-115K XUNPU TF-109 HOAUC HYC77-TF09-200
Compatible connectors: JAE DX07S016JA1R1500 JAE DX07S016JA3R1500 HROPARTS TYPE-C-31-M-12 HROPARTS TYPE-C-31-M-14 XKB U262-161N-4BVC11 Jing Ext. C167321
ONLY 1 OF THE RGB LEDS SHOULD BE PLACED
Partially compatible (signals only) Hirose DM3AT-SF-PEJM5 Kyocera 045138008100858+ Yamaichi PJS008-4100-0-VE

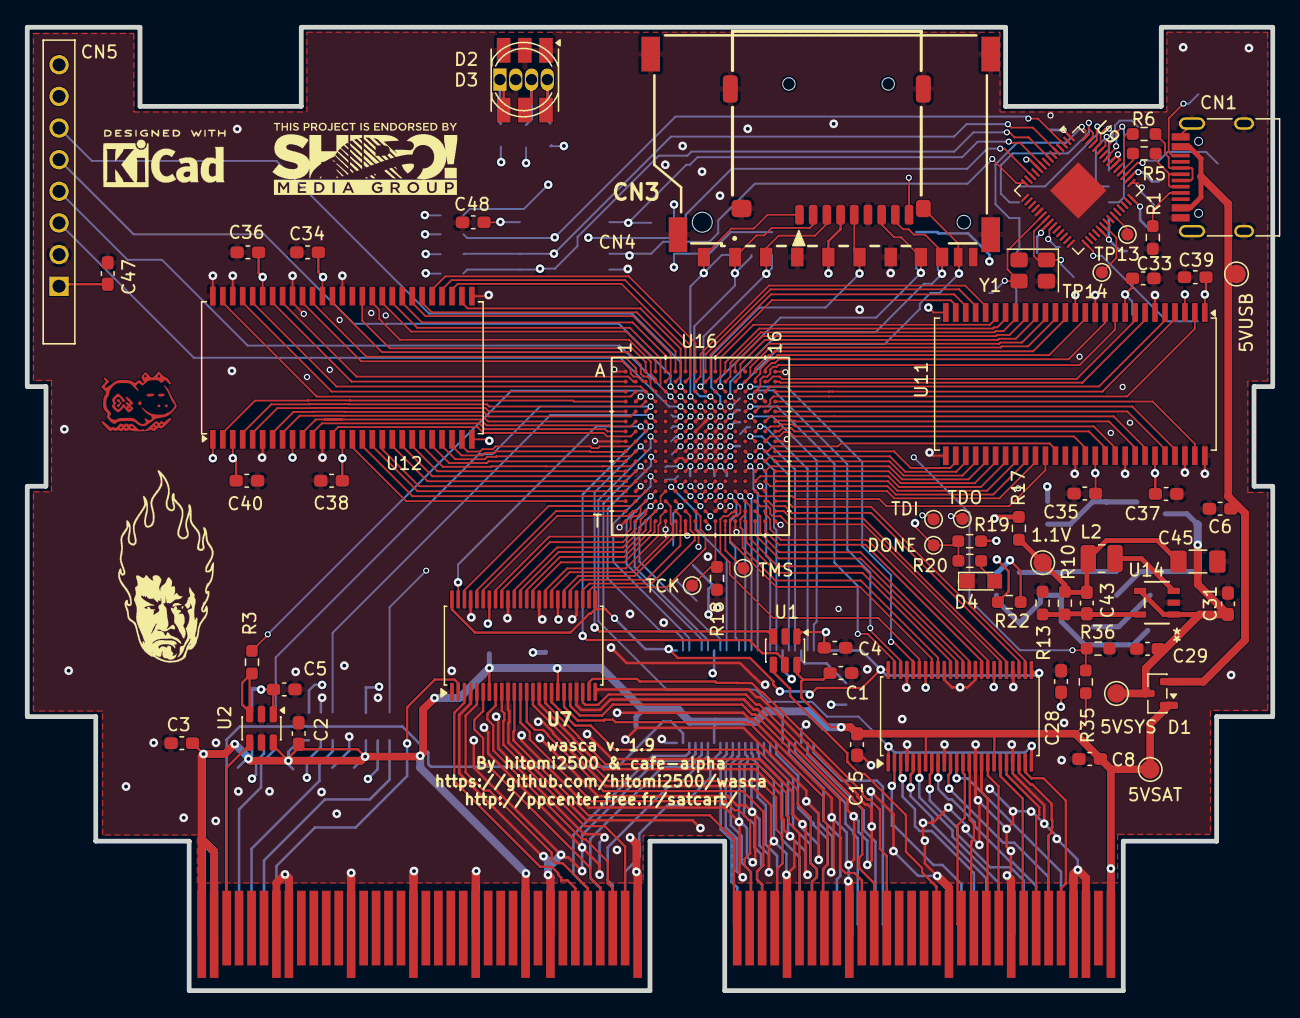
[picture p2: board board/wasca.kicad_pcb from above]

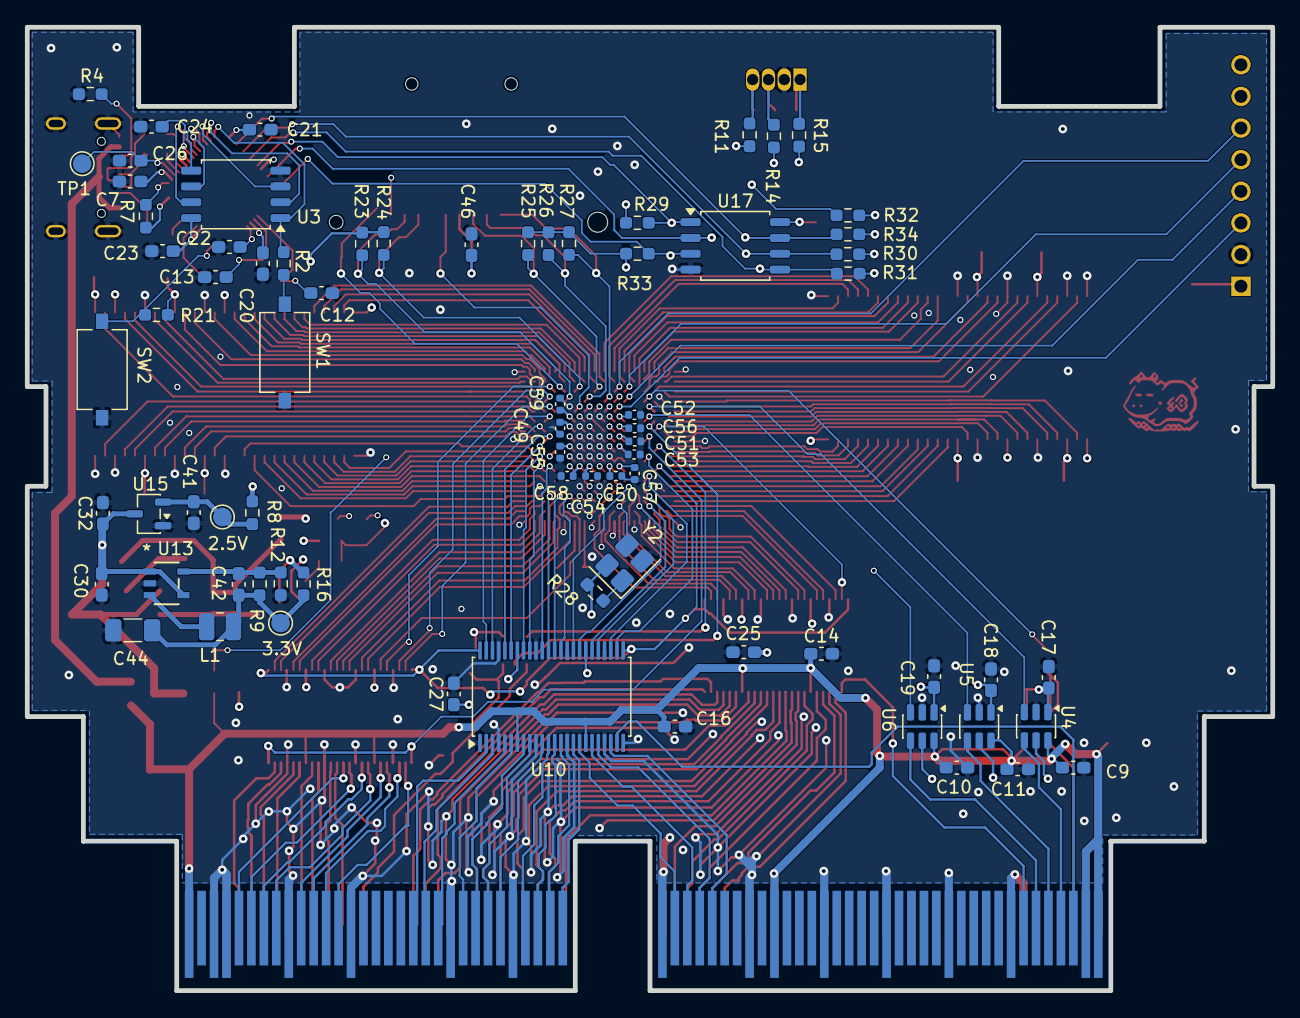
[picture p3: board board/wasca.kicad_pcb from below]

Board: 4 copper layers, 100.0 x 77.4 mm, 145 parts (74 on the bottom side), 256 nets.

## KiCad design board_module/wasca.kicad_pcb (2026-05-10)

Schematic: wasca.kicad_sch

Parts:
C1, C2, C4, C5, C21, C22, C23, C25, C26, C38, C39, C42, C43, C44, C45, C46, C47, C48, C49, C50, C51, C52, C53, C55: 0.1uF; C_0603_1608Metric_Pad1.08x0.95mm_HandSolder
C3, C17, C54: 4.7uF; C_0603_1608Metric_Pad1.08x0.95mm_HandSolder
C24: 10uF; C_1206_3216Metric_Pad1.33x1.80mm_HandSolder
CHAMFER_WARN1, CHAMFER_WARN2: CHAMFER_WARNING
CN1: CARTRIDGE_EDGE_CONNECTOR; CARTRIDGE_EDGE_CONNECTOR2
CN2: TFP09-2-12B; TFP09212B; Manufacturer_Part_Number TFP09-2-12B
CN3: Conn_02x02_Odd_Even; PinHeader_2x02_P2.54mm_Vertical
CN4: SODIMM-200; Conn_TE-DDR2-SODIMM-0.6-200P-doublesided
CN5: 693063020911; PART-NUMBER 693063020911
CN6: Conn_01x02_Pin; PinHeader_1x02_P2.54mm_Vertical
D1: LED_BKGR; LED_D5.0mm-4_RGB
D2: LED_RGB; LED_RGB_5050-6
D4: BAT54C; SOT-23
KICAD1: KICAD_LOGO; DESIGNED_WITH_KICAD_10X05
R4: 4K7; R_0603_1608Metric_Pad0.98x0.95mm_HandSolder
R5: 10K; R_0603_1608Metric_Pad0.98x0.95mm_HandSolder
R8, R9, R15, R16, R17: 33K; R_0603_1608Metric_Pad0.98x0.95mm_HandSolder
R10, R11, R19: 470; R_0603_1608Metric_Pad0.98x0.95mm_HandSolder
R21: 0; R_0603_1608Metric_Pad0.98x0.95mm_HandSolder
SEGATA1: LOGO; Segata_Sanshiro
SHIRO!1: SHIRO_LOGO; SHIRO!
U1, U2, U5: 74ALVC164245; TSSOP-48_6.1x12.5mm_P0.5mm
U3: MT48LC16M16A2TG; TSOP-II-54_22.2x10.16mm_P0.8mm
U4: LD1117S33TR_SOT223; SOT-223-3_TabPin2
U6: IS66WVH8M8ALL-166B1LI; BGA25C100P5X5_800X600X120N; PARTREV B2
U8, U9, U10, U11, U12: SN74LVC1T45DBV; SOT-23-6
U13: ESP32_CAM_HALF; MODULE_ESP32-CAM-HALF
VACHE1: LOGO; LOGO_VACHE_SIM

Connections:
/5V_SATURN_DETECT: CN4.54, R4.2, R5.1
/+3_3V: C1.1, C4.1, C5.1, C21.1, C24.1, C25.1, C39.1, C42.1, C44.1, C46.1, C48.1, C50.1, CN2.4 (VDD), CN3.2, CN5.4 (VDD), R8.1, R9.1, R15.1, R16.1, R17.1, U1.31 (VCCA), U1.42 (VCCA), U2.31 (VCCA), U2.42 (VCCA), U3.1 (VDD), U3.3 (VDDQ), U3.9 (VDDQ), U3.14 (VDD), U3.27 (VDD), U3.43 (VDDQ), U3.49 (VDDQ), U4.2 (VO), U5.31 (VCCA), U5.42 (VCCA), U6.B4 (VCC), U6.D1 (VCCQ), U6.E4 (VCCQ__1), U8.1 (VCCA), U9.1 (VCCA), U9.5 (DIR), U10.1 (VCCA), U10.5 (DIR), U11.1 (VCCA), U12.1 (VCCA), U12.5 (DIR)
/+5V_SATURN: C2.1, C3.1, C17.1, C22.1, C26.1, C43.1, C45.1, C47.1, C49.1, C51.1, CN1.A1 (VCC), CN1.A2 (VCC), CN1.A27 (VCC), CN1.A67 (VCC), CN1.B1 (VCC), CN1.B2 (VCC), CN1.B27 (VCC), CN1.B67 (VCC), D4.1, R4.1, U1.7 (VCCB), U1.18 (VCCB), U2.7 (VCCB), U2.18 (VCCB), U5.7 (VCCB), U5.18 (VCCB), U8.6 (VCCB), U9.6 (VCCB), U10.6 (VCCB), U11.6 (VCCB), U12.6 (VCCB)
/+5V_SYS: C23.1, C38.1, C52.1, C53.1, C54.1, C55.1, CN3.4, CN4.2, CN4.4, CN4.6, CN4.8, CN4.10, CN4.12, D4.3, U4.3 (VI), U13.1 (5V)
/ABUS_3V_A1: CN4.51, U1.43 (1A3)
/ABUS_3V_A2: CN4.103, U2.30 (2A4)
/ABUS_3V_A3: CN4.109, U2.32 (2A3)
/ABUS_3V_A4: CN4.111, U2.33 (2A2)
/ABUS_3V_A5: CN4.113, U2.35 (2A1)
/ABUS_3V_A6: CN4.115, U2.36 (2A0)
/ABUS_3V_A7: CN4.117, U2.37 (1A7)
/ABUS_3V_A8: CN4.65, U1.37 (1A7)
/ABUS_3V_A9: CN4.63, U1.38 (1A6)
/ABUS_3V_A10: CN4.49, U1.41 (1A4)
/ABUS_3V_A11: CN4.41, U1.40 (1A5)
/ABUS_3V_A12: CN4.69, U1.35 (2A1)
/ABUS_3V_A13: CN4.67, U1.36 (2A0)
/ABUS_3V_A14: CN4.119, U2.38 (1A6)
/ABUS_3V_A15: CN4.71, U1.33 (2A2)
/ABUS_3V_A16: CN4.121, U2.40 (1A5)
/ABUS_3V_A17: CN4.87, U1.32 (2A3)
/ABUS_3V_A18: CN4.123, U2.41 (1A4)
/ABUS_3V_A19: CN4.85, U1.30 (2A4)
/ABUS_3V_A20: CN4.125, U2.43 (1A3)
/ABUS_3V_A21: CN4.83, U1.29 (2A5)
/ABUS_3V_A22: CN4.127, U2.44 (1A2)
/ABUS_3V_A23: CN4.81, U1.27 (2A6)
/ABUS_3V_A24: CN4.129, U2.46 (1A1)
/ABUS_3V_CS0: CN4.57, U1.44 (1A2)
/ABUS_3V_CS1: CN4.99, U2.27 (2A6)
/ABUS_3V_CS2: CN4.59, U1.46 (1A1)
/ABUS_3V_D0: CN4.88, U5.47 (1A0)
/ABUS_3V_D1: CN4.86, U5.46 (1A1)
/ABUS_3V_D2: CN4.84, U5.44 (1A2)
/ABUS_3V_D3: CN4.82, U5.43 (1A3)
/ABUS_3V_D4: CN4.66, U5.32 (2A3)
/ABUS_3V_D5: CN4.68, U5.33 (2A2)
/ABUS_3V_D6: CN4.70, U5.35 (2A1)
/ABUS_3V_D7: CN4.72, U5.36 (2A0)
/ABUS_3V_D8: CN4.80, U5.41 (1A4)
/ABUS_3V_D9: CN4.78, U5.40 (1A5)
/ABUS_3V_D10: CN4.76, U5.38 (1A6)
/ABUS_3V_D11: CN4.74, U5.37 (1A7)
/ABUS_3V_D12: CN4.58, U5.26 (2A7)
/ABUS_3V_D13: CN4.60, U5.27 (2A6)
/ABUS_3V_D14: CN4.62, U5.29 (2A5)
/ABUS_3V_D15: CN4.64, U5.30 (2A4)
/ABUS_3V_IRQ: CN4.93, U8.3 (A)
/ABUS_3V_MUX_DATA_DIR: CN4.91, U5.1 (1DIR), U5.24 (2DIR)
/ABUS_3V_RD: CN4.101, U2.29 (2A5)
/ABUS_3V_WR0: CN4.61, U1.47 (1A0)
/ABUS_3V_WR1: CN4.97, U2.26 (2A7)
/ABUS_A1: CN1.A45 (AA1), U1.6 (1B3)
/ABUS_A2: CN1.B44 (AA2), U2.19 (2B4)
/ABUS_A3: CN1.B43 (AA3), U2.17 (2B3)
/ABUS_A4: CN1.B42 (AA4), U2.16 (2B2)
/ABUS_A5: CN1.B40 (AA5), U2.14 (2B1)
/ABUS_A6: CN1.B39 (AA6), U2.13 (2B0)
/ABUS_A7: CN1.B38 (AA7), U2.12 (1B7)
/ABUS_A8: CN1.A40 (AA8), U1.12 (1B7)
/ABUS_A9: CN1.A42 (AA9), U1.11 (1B6)
/ABUS_A10: CN1.A44 (AA10), U1.8 (1B4)
/ABUS_A11: CN1.A43 (AA11), U1.9 (1B5)
/ABUS_A12: CN1.A38 (AA12), U1.14 (2B1)
/ABUS_A13: CN1.A39 (AA13), U1.13 (2B0)
/ABUS_A14: CN1.B37 (AA14), U2.11 (1B6)
/ABUS_A15: CN1.A37 (AA15), U1.16 (2B2)
/ABUS_A16: CN1.B35 (AA16), U2.9 (1B5)
/ABUS_A17: CN1.A35 (AA17), U1.17 (2B3)
/ABUS_A18: CN1.B34 (AA18), U2.8 (1B4)
/ABUS_A19: CN1.A34 (AA19), U1.19 (2B4)
/ABUS_A20: CN1.B33 (AA20), U2.6 (1B3)
/ABUS_A21: CN1.A33 (AA21), U1.20 (2B5)
/ABUS_A22: CN1.B32 (AA22), U2.5 (1B2)
/ABUS_A23: CN1.A32 (AA23), U1.22 (2B6)
/ABUS_A24: CN1.B31 (AA24), U2.3 (1B1)
/ABUS_CS0: CN1.A47 (ACS0), U1.5 (1B2)
/ABUS_CS1: CN1.B48 (ACS1), U2.22 (2B6)
/ABUS_CS2: CN1.A48 (ACS2), U1.3 (1B1)
/ABUS_D0: CN1.A55 (AD0), U5.2 (1B0)
/ABUS_D1: CN1.A56 (AD1), U5.3 (1B1)
/ABUS_D2: CN1.A57 (AD2), U5.5 (1B2)
/ABUS_D3: CN1.A58 (AD3), U5.6 (1B3)
/ABUS_D4: CN1.B58 (AD4), U5.17 (2B3)
/ABUS_D5: CN1.B57 (AD5), U5.16 (2B2)
/ABUS_D6: CN1.B56 (AD6), U5.14 (2B1)
/ABUS_D7: CN1.B55 (AD7), U5.13 (2B0)
/ABUS_D8: CN1.A60 (AD8), U5.8 (1B4)
/ABUS_D9: CN1.A61 (AD9), U5.9 (1B5)
/ABUS_D10: CN1.A62 (AD10), U5.11 (1B6)
/ABUS_D11: CN1.A63 (AD11), U5.12 (1B7)
/ABUS_D12: CN1.B63 (AD12), U5.23 (2B7)
/ABUS_D13: CN1.B62 (AD13), U5.22 (2B6)
/ABUS_D14: CN1.B61 (AD14), U5.20 (2B5)
/ABUS_D15: CN1.B60 (AD15), U5.19 (2B4)
/ABUS_IRQ: CN1.B53 (AIRQ), U8.4 (B)
/ABUS_RD: CN1.B47 (ARD), U2.20 (2B5)
/ABUS_WR0: CN1.A49 (AWR0), U1.2 (1B0)
/ABUS_WR1: CN1.B49 (AWR1), U2.23 (2B7)
/BUFFERS_OE: CN4.77, U1.25 (2OE), U1.48 (1OE), U2.25 (2OE), U2.48 (1OE), U5.25 (2OE), U5.48 (1OE)
/ESP32_CS: CN4.151, U13.5 (IO15)
/ESP32_MISO: CN4.155, U13.3 (IO12)
/ESP32_MOSI: CN4.153, U13.4 (IO13)
/ESP32_SCK: CN4.149, U13.6 (IO14)
/IBCK: CN1.A5 (IBCK), U10.4 (B)
/IBCK_3V: CN4.137, U10.3 (A)
/ILRCK: CN1.A6 (ILRCK), U12.4 (B)
/ILRCK_3V: CN4.135, U12.3 (A)
/IRQ_OUT_ENABLE: CN4.95, CN4.131, U8.5 (DIR)
/ISD: CN1.A4 (ISD), U9.4 (B)
/ISD_3V: CN4.139, U9.3 (A)
/LEDB: CN4.94, R19.1
/LEDG: CN4.92, R11.1
/LEDR: CN4.90, R10.1
/RESET: CN1.A3 (SYSRES), U1.23 (2B7)
/RESET_3V: CN4.79, U1.26 (2A7)
/SCSPCLK: CN1.A7 (SCSPCLK), CN4.133
/SDRAM_AUX_A0: CN4.154, U3.23 (A0), U6.E3 (DQ5)
/SDRAM_AUX_A1: CN4.148, U3.24 (A1), U6.E2 (DQ6)
/SDRAM_AUX_A2: CN4.152, U3.25 (A2), U6.D3 (DQ0)
/SDRAM_AUX_A3: CN4.156, U3.26 (A3)
/SDRAM_AUX_A4: CN4.146, U3.29 (A4)
/SDRAM_AUX_A5: CN4.145, U3.30 (A5)
/SDRAM_AUX_A6: CN4.143, U3.31 (A6)
/SDRAM_AUX_A7: CN4.141, U3.32 (A7)
/SDRAM_AUX_A8: CN4.142, U3.33 (A8)
/SDRAM_AUX_A9: CN4.138, U3.34 (A9)
/SDRAM_AUX_A10: CN4.144, U3.22 (A10), U6.E1 (DQ7)
/SDRAM_AUX_A11: CN4.134, U3.35 (A11)
/SDRAM_AUX_A12: CN4.130, U3.36 (A12)
/SDRAM_AUX_BA0: CN4.136, U3.20 (BA0), U6.B2 (CK)
/SDRAM_AUX_BA1: CN4.140, U3.21 (BA1), U6.D2 (DQ1)
/SDRAM_AUX_CAS: CN4.120, U3.17 (~CAS)
/SDRAM_AUX_CKE: CN4.128, U3.37 (CKE)
/SDRAM_AUX_CLK: CN4.126, U3.38 (CLK)
/SDRAM_AUX_CS: CN4.132, U3.19 (~CS), U6.B1 (~CK)
/SDRAM_AUX_DQ0: CN4.96, U3.2 (DQ0)
/SDRAM_AUX_DQ1: CN4.98, U3.4 (DQ1)
/SDRAM_AUX_DQ2: CN4.100, U3.5 (DQ2)
/SDRAM_AUX_DQ3: CN4.102, U3.7 (DQ3), U6.D5 (DQ4)
/SDRAM_AUX_DQ4: CN4.104, U3.8 (DQ4), U6.D4 (DQ3)
/SDRAM_AUX_DQ5: CN4.110, U3.10 (DQ5), U6.C4 (DQ2)
/SDRAM_AUX_DQ6: CN4.112, U3.11 (DQ6), U6.A4 (~RESET)
/SDRAM_AUX_DQ7: CN4.114, U3.13 (DQ7), U6.C3 (RWDS)
/SDRAM_AUX_DQM0: CN4.116, U3.15 (DQML), U6.A3 (~CS)
/SDRAM_AUX_DQM1: CN4.122, U3.39 (DQMH)
/SDRAM_AUX_RAS: CN4.124, U3.18 (~RAS)
/SDRAM_AUX_WE: CN4.118, U3.16 (~WE)
/SD_CLK: CN2.5 (CLK), CN4.46, CN5.5 (CLK)
/SD_CMD: CN2.3 (CMD), CN4.48, CN5.2 (CMD), R15.2
/SD_DAT0: CN2.7 (DAT0), CN4.44, CN5.7 (DAT0), R9.2
/SD_DAT1: CN2.8 (DAT1), CN4.42, CN5.8 (DAT1), R8.2
/SD_DAT2: CN2.1 (DAT2), CN4.52, CN5.9 (DAT2), R17.2
/SD_DAT3: CN2.2 (DAT3/CD), CN4.50, CN5.1 (CD/DAT3), R16.2
/SD_DET_A: CN2.10 (GND), CN4.73, CN5.CD
/SD_DET_B: CN2.9 (CARD_DETECTION), CN4.75
/SSEL: CN1.B3 (SSEL), U11.4 (B)
/SSEL_3V: CN4.147, R21.1
/TEST_1: CN4.89, CN6.1
/TEST_2: CN4.150, CN6.2
GND: C1.2, C2.2, C3.2, C4.2, C5.2, C17.2, C21.2, C22.2, C23.2, C24.2, C25.2, C26.2, C38.2, C39.2, C42.2, C43.2, C44.2, C45.2, C46.2, C47.2, C48.2, C49.2, C50.2, C51.2, C52.2, C53.2, C54.2, C55.2, CN1.A8 (GND), CN1.A13 (GND), CN1.A18 (GND), CN1.A23 (GND), CN1.A29 (GND), CN1.A36 (GND), CN1.A41 (GND), CN1.A46 (GND), CN1.A54 (GND), CN1.A59 (GND), CN1.A64 (GND), CN1.A65 (GND), CN1.B7 (GND), CN1.B8 (GND), CN1.B13 (GND), CN1.B18 (GND), CN1.B23 (GND), CN1.B29 (GND), CN1.B36 (GND), CN1.B41 (GND), CN1.B46 (GND), CN1.B54 (GND), CN1.B59 (GND), CN1.B64 (GND), CN1.B65 (GND), CN2.6 (VSS), CN2.11 (SHIELD), CN2.12 (SHIELD), CN2.13 (SHIELD), CN3.1, CN3.3, CN4.1, CN4.3, CN4.5, CN4.7, CN4.9, CN4.11, CN4.39, CN4.40, CN4.55, CN4.56, CN4.105, CN4.106, CN4.107, CN4.108, CN4.157, CN4.158, CN4.199, CN4.200, CN5.3 (VSS1), CN5.6 (VSS2), CN5.S1, CN5.S2, CN5.S3, CN5.S4, D1.2 (K), D2.1 (RK), D2.2 (GK), D2.3 (BK), R5.2, U1.1 (1DIR), U1.4 (GND), U1.10 (GND), U1.15 (GND), U1.21 (GND), U1.24 (2DIR), U1.28 (GND), U1.34 (GND), U1.39 (GND), U1.45 (GND), U2.1 (1DIR), U2.2 (1B0), U2.4 (GND), U2.10 (GND), U2.15 (GND), U2.21 (GND), U2.24 (2DIR), U2.28 (GND), U2.34 (GND), U2.39 (GND), U2.45 (GND), U3.6 (VSSQ), U3.12 (VSSQ), U3.28 (VSS), U3.41 (VSS), U3.46 (VSSQ), U3.52 (VSSQ), U3.54 (VSS), U4.1 (GND), U5.4 (GND), U5.10 (GND), U5.15 (GND), U5.21 (GND), U5.28 (GND), U5.34 (GND), U5.39 (GND), U5.45 (GND), U6.B3 (VSS), U6.C1 (VSSQ), U6.E5 (VSSQ__1), U8.2 (GND), U9.2 (GND), U10.2 (GND), U11.2 (GND), U11.5 (DIR), U12.2 (GND), U13.2 (GND)
unnamed: D1.1 (BA), D2.4 (BA), R19.2
unnamed: D1.3 (GA), D2.5 (GA), R11.2
unnamed: D1.4 (RA), D2.6 (RA), R10.2
unnamed: R21.2, U11.3 (A)

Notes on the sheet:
SDRAM : shares 3V3 with MAX10 DDR : requires 2V5 power supply
--- Changelog --- V1.0 hitomi2500 : - Initial version with 10M04SFE, SDRAM, FT201XS V1.1 hitomi2500 : - Both DDR/SDRAM support - Added USB and bluetooth support - Sound I/O mapped to MAX10 V1.2 cafe-alpha : - Changed PCB shape and ICs position in order to fit Action Replay case - Changed MAX10 chip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
External 5V power supply + 3V3 power output/check
MFG P/N : 1473005-4 1565917-4
Compatible connectors: Hroparts TF-01A SOFNG TF-15x15 SOFNG TF-015 XUNPU TF-115K XUNPU TF-109 HOAUC HYC77-TF09-200
ONLY 1 OF THE RGB LEDS SHOULD BE PLACED
Partially compatible (signals only) Hirose DM3AT-SF-PEJM5 Kyocera 045138008100858+ Yamaichi PJS008-4100-0-VE

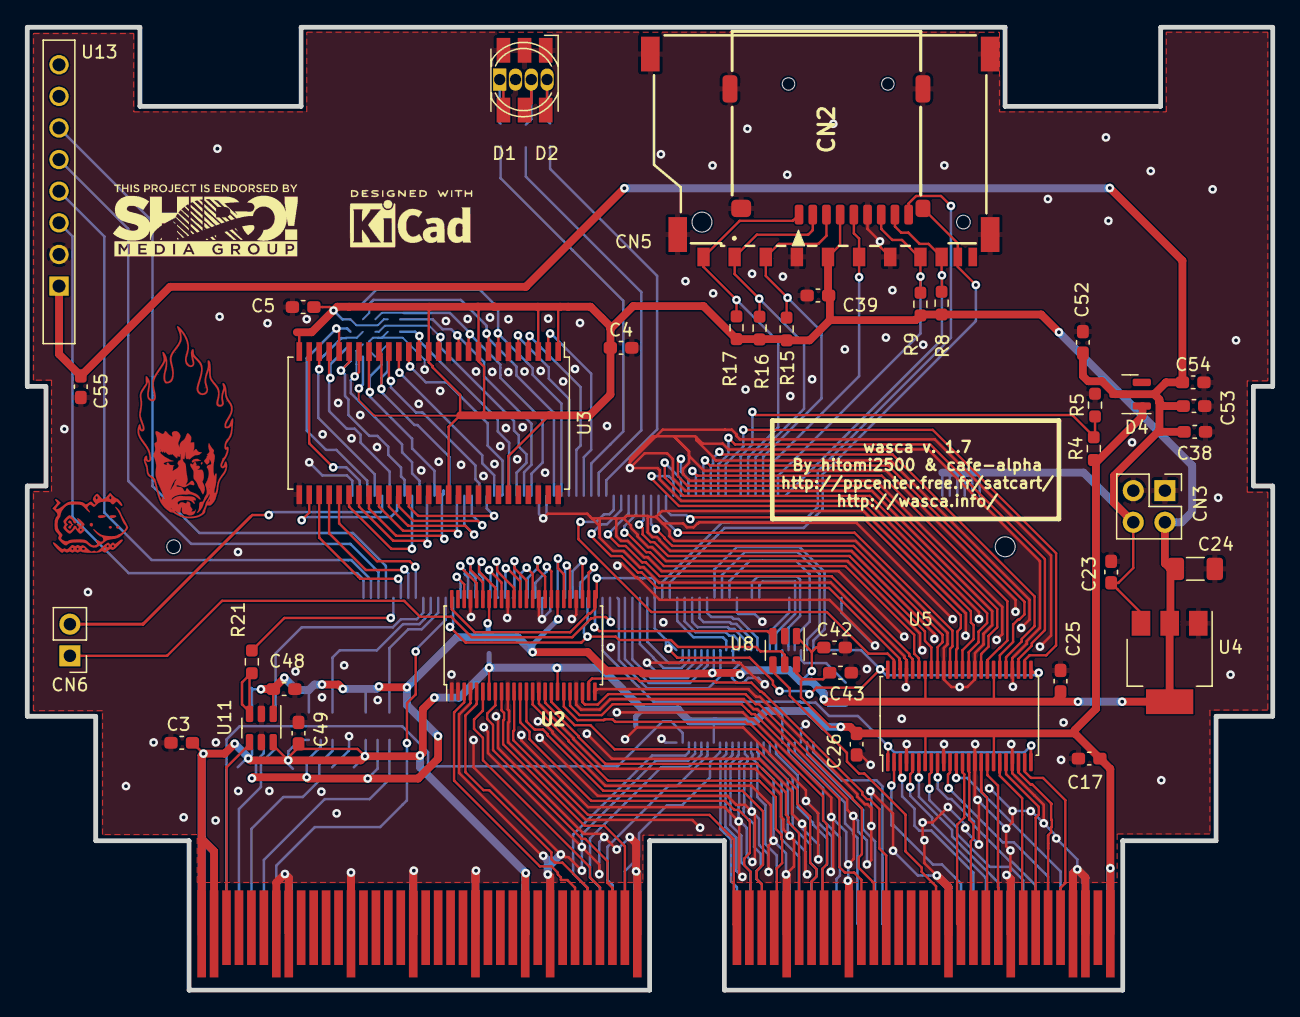
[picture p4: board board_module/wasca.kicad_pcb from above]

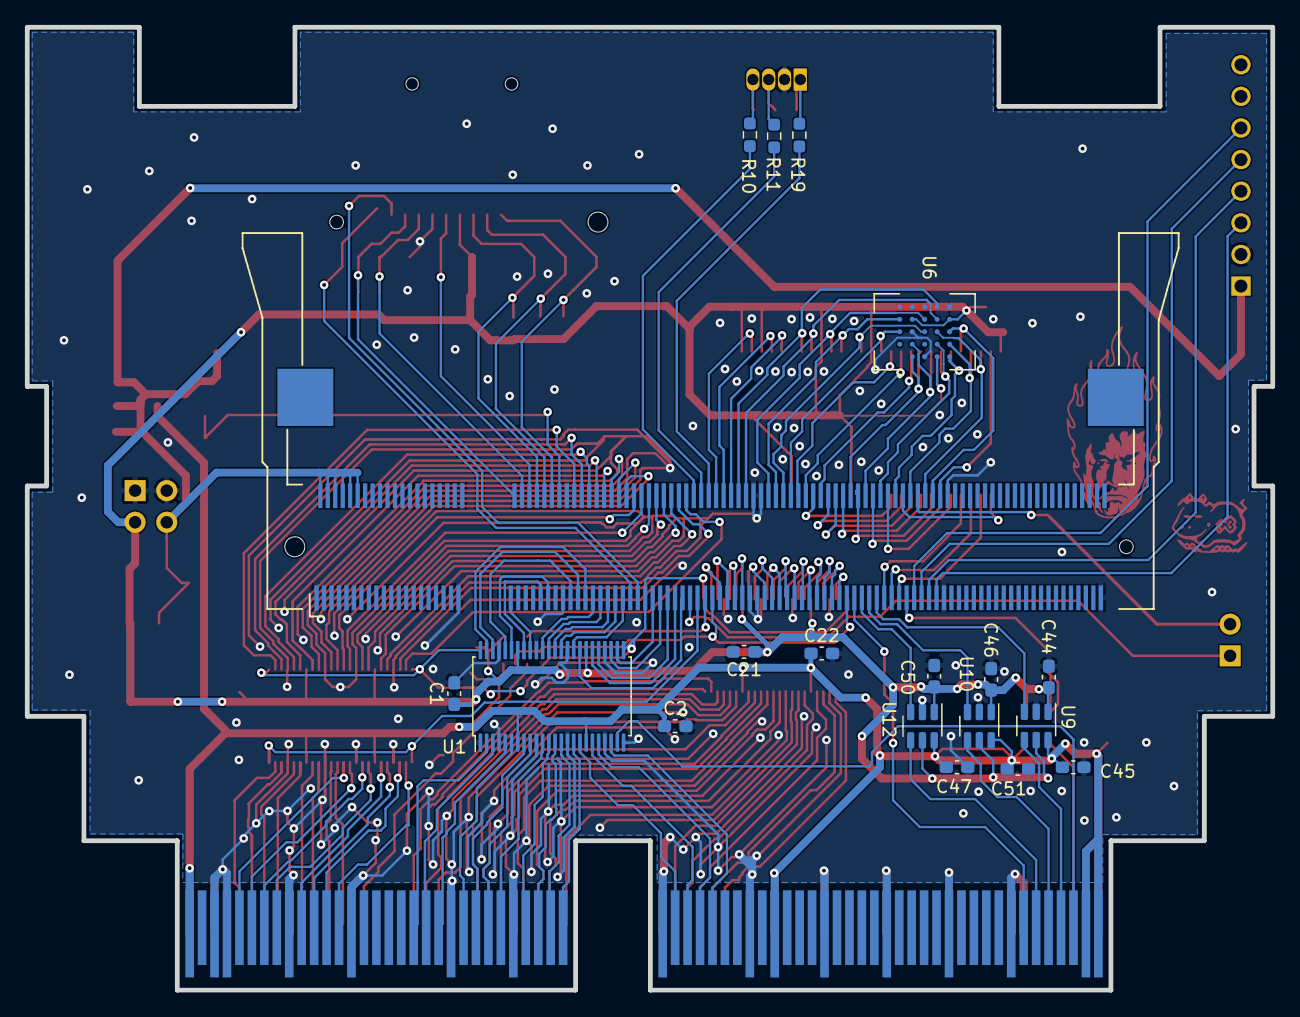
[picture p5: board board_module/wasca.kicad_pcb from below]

Board: 2 copper layers, 100.1 x 77.4 mm, 66 parts (20 on the bottom side), 165 nets.

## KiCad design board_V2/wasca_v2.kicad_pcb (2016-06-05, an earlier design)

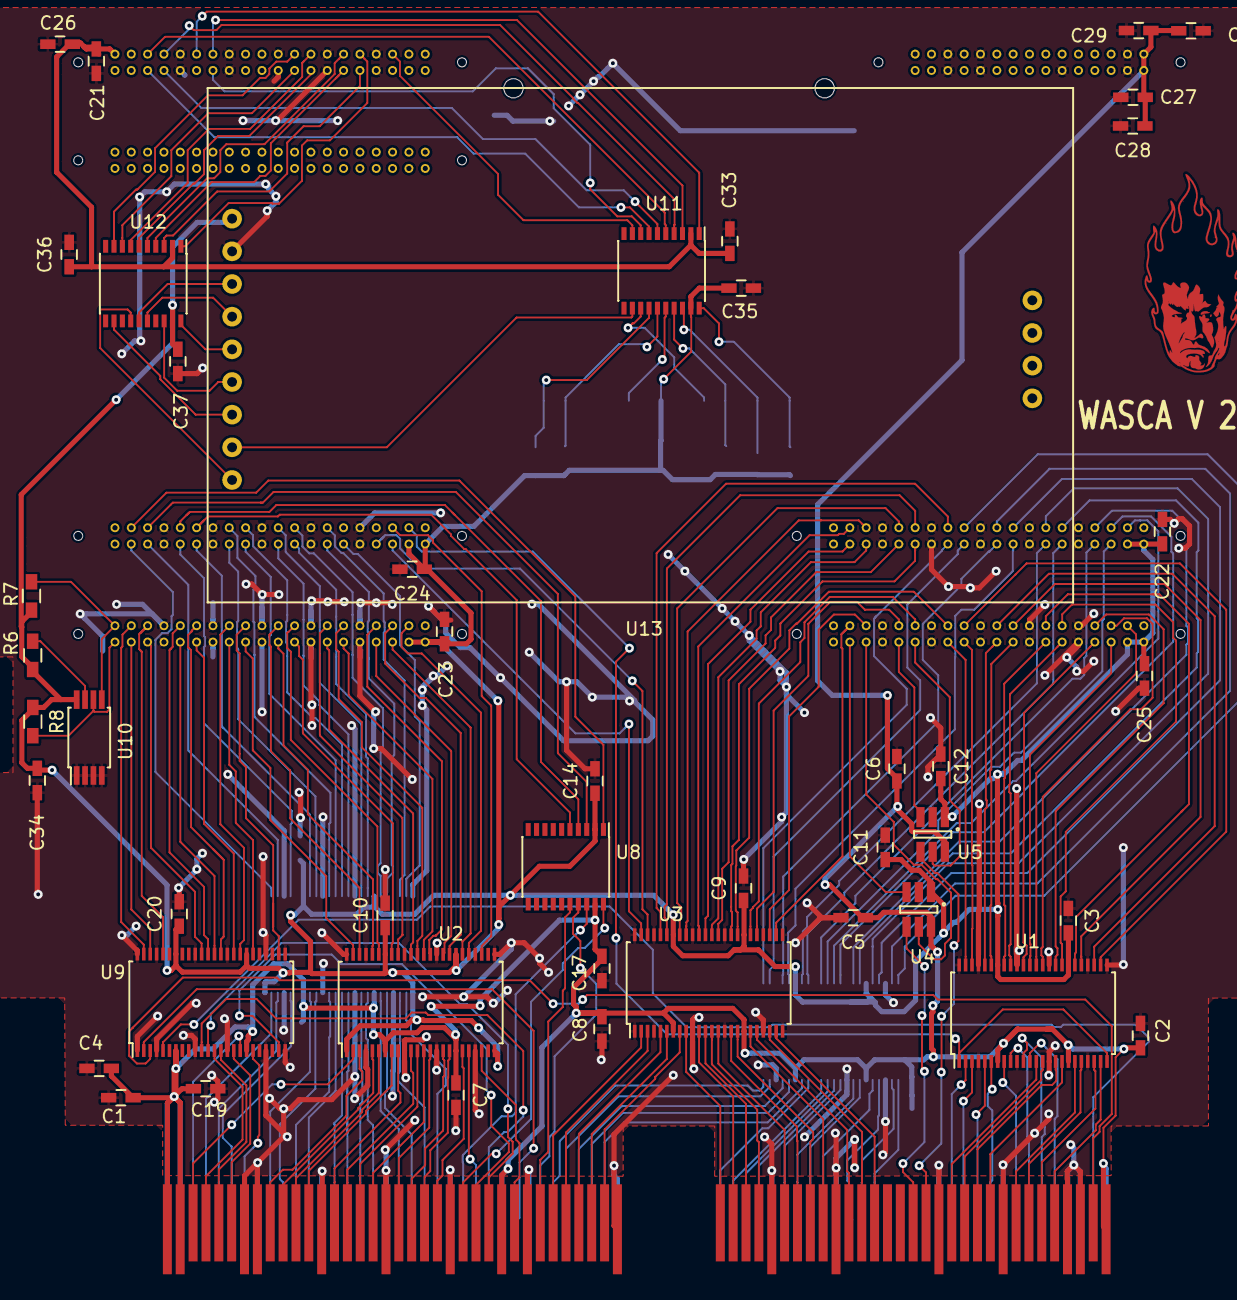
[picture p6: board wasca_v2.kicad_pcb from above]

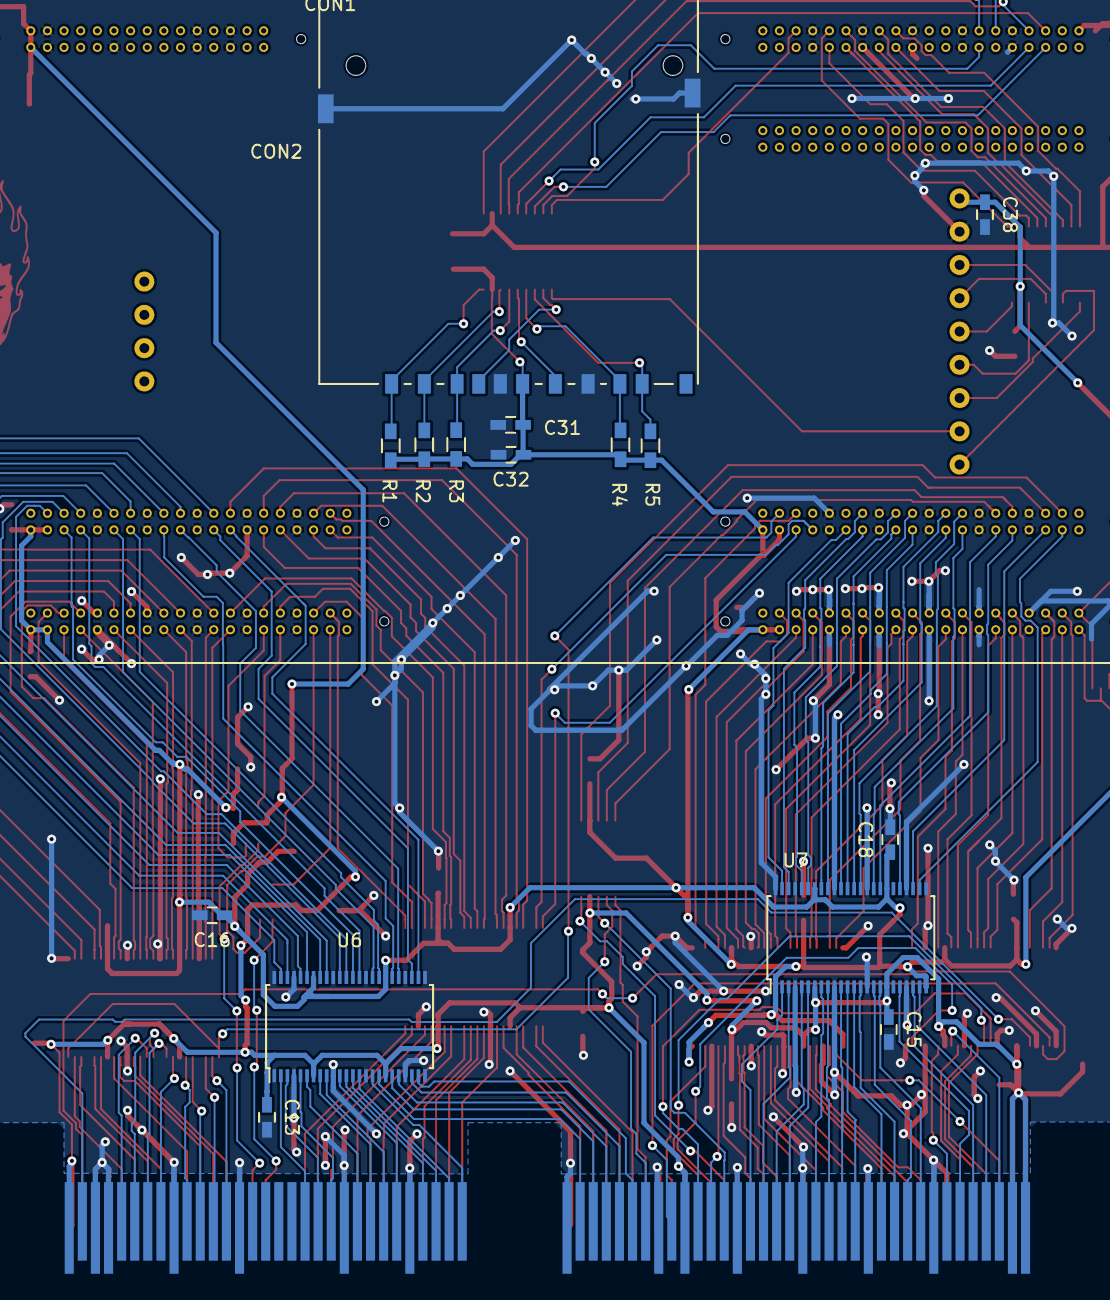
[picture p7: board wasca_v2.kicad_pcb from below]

Board: 2 copper layers, 62 parts (16 on the bottom side), 230 nets.

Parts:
C1, C26, C28, C30: 10uF; C_0603_HandSoldering
C2, C3, C4, C5, C6, C7, C8, C9, C10, C11, C12, C13, C14, C15, C16, C17, C18, C19, C20, C21, C22, C23, C24, C25, C27, C29, C32, C33, C34, C35, C36, C37, C38: 0.1uF; C_0603_HandSoldering
C31: 1uF; C_0603_HandSoldering
CN1: CARTRIDGE_EDGE_CONNECTOR; CARTRIDGE_EDGE_CONNECTOR2
CON1: SnickerDoodle
CON2: SD_Card; SD_Card_Receptacle
R1, R2, R3, R4, R5: 50K; R_0603_HandSoldering
R6: 0; R_0603_HandSoldering
R7, R8: 10K; R_0603_HandSoldering
U1, U2, U3, U6, U7, U9: 74ALVC164245; TSSOP-48_6.1x12.5mm_Pitch0.5mm
U4, U5: 74LVC1T45GW,125; SOT-23-6_Handsoldering
U8, U11, U12: TXS0108EPWR; SSOP-20_4.4x6.5mm_Pitch0.65mm
U10: M24C04-WDW6TP; TSSOP-8_4.4x3mm_Pitch0.65mm
U13: ILI9341_LCD_Breakout

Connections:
/+1_8V: C21.1, C26.1, C33.1, C36.1, CON1.B1, U11.2, U12.2
/+3_3V: C3.1, C9.1, C10.1, C11.1, C12.1, C14.1, C16.1, C18.1, C20.1, C22.1, C23.1, C24.1, C25.1, C31.1, C32.1, C34.1, C35.1, C37.1, C38.1, CON1.C1, CON1.C3, CON1.D1, CON1.D3, CON1.E1, CON1.E3, CON1.F1, CON1.F3, CON2.4, R1.1, R2.1, R3.1, R4.1, R5.1, R6.1, R7.1, R8.1, U1.31, U1.42, U2.1, U2.24, U2.31, U2.42, U3.31, U3.42, U4.1, U5.1, U6.31, U6.42, U7.1, U7.24, U7.31, U7.42, U8.2, U9.31, U9.42, U10.8, U11.19, U12.19, U13.1
/+5V: C1.1, C2.1, C4.1, C5.1, C6.1, C7.1, C8.1, C13.1, C15.1, C17.1, C19.1, C27.1, C28.1, C29.1, C30.1, CN1.A1, CN1.A2, CN1.A27, CN1.A67, CN1.B1, CN1.B2, CN1.B27, CN1.B67, CON1.A29, CON1.A30, U1.7, U1.18, U2.7, U2.18, U3.7, U3.18, U4.6, U5.6, U6.7, U6.18, U7.7, U7.18, U8.19, U9.7, U9.18
/ABUS_A0: CN1.B45, U3.19
/ABUS_A0_3V: CON1.E30, U3.30
/ABUS_A1: CN1.A45, U6.6
/ABUS_A1_3V: CON1.F14, U6.43
/ABUS_A2: CN1.B44, U3.17
/ABUS_A2_3V: CON1.E26, U3.32
/ABUS_A3: CN1.B43, U3.16
/ABUS_A3_3V: CON1.F29, U3.33
/ABUS_A4: CN1.B42, U3.14
/ABUS_A4_3V: CON1.F31, U3.35
/ABUS_A5: CN1.B40, U3.13
/ABUS_A5_3V: CON1.F35, U3.36
/ABUS_A6: CN1.B39, U3.12
/ABUS_A6_3V: CON1.F37, U3.37
/ABUS_A7: CN1.B38, U3.11
/ABUS_A7_3V: CON1.F38, U3.38
/ABUS_A8: CN1.A40, U6.12
/ABUS_A8_3V: CON1.F4, U6.37
/ABUS_A9: CN1.A42, U6.11
/ABUS_A9_3V: CON1.F6, U6.38
/ABUS_A10: CN1.A44, U6.8
/ABUS_A10_3V: CON1.F12, U6.41
/ABUS_A11: CN1.A43, U6.9
/ABUS_A11_3V: CON1.F8, U6.40
/ABUS_A12: CN1.A38, U6.14
/ABUS_A12_3V: CON1.F7, U6.35
/ABUS_A13: CN1.A39, U6.13
/ABUS_A13_3V: CON1.F5, U6.36
/ABUS_A14: CN1.B37, U3.9
/ABUS_A14_3V: CON1.F36, U3.40
/ABUS_A15: CN1.A37, U6.16
/ABUS_A15_3V: CON1.F11, U6.33
/ABUS_A16: CN1.B35, U3.8
/ABUS_A16_3V: CON1.F32, U3.41
/ABUS_A17: CN1.A35, U6.17
/ABUS_A17_3V: CON1.F13, U6.32
/ABUS_A18: CN1.B34, U3.6
/ABUS_A18_3V: CON1.F30, U3.43
/ABUS_A19: CN1.A34, U6.19
/ABUS_A19_3V: CON1.F17, U6.30
/ABUS_A20: CN1.B33, U3.5
/ABUS_A20_3V: CON1.F26, U3.44
/ABUS_A21: CN1.A33, U6.20
/ABUS_A21_3V: CON1.F19, U6.29
/ABUS_A22: CN1.B32, U3.3
/ABUS_A22_3V: CON1.D7, U3.46
/ABUS_A23: CN1.A32, U6.22
/ABUS_A23_3V: CON1.F23, U6.27
/ABUS_A24: CN1.B31, U3.2
/ABUS_A24_3V: CON1.D5, U3.47
/ABUS_A25: CN1.A31, U6.23
/ABUS_A25_3V: CON1.F25, U6.26
/ABUS_CS0: CN1.A47, U6.5
/ABUS_CS0_3V: CON1.F18, U6.44
/ABUS_CS1: CN1.B48, U3.22
/ABUS_CS1_3V: CON1.E36, U3.27
/ABUS_CS2: CN1.A48, U6.3
/ABUS_CS2_3V: CON1.F20, U6.46
/ABUS_D0: CN1.A55, U1.2
/ABUS_D0_3V: CON1.E25, U1.47
/ABUS_D1: CN1.A56, U1.3
/ABUS_D1_3V: CON1.E23, U1.46
/ABUS_D2: CN1.A57, U1.5
/ABUS_D2_3V: CON1.E19, U1.44
/ABUS_D3: CN1.A58, U1.6
/ABUS_D3_3V: CON1.E17, U1.43
/ABUS_D4: CN1.B58, U1.17
/ABUS_D4_3V: CON1.E12, U1.32
/ABUS_D5: CN1.B57, U1.16
/ABUS_D5_3V: CON1.E8, U1.33
/ABUS_D6: CN1.B56, U1.14
/ABUS_D6_3V: CON1.E6, U1.35
/ABUS_D7: CN1.B55, U1.13
/ABUS_D7_3V: CON1.E4, U1.36
/ABUS_D8: CN1.A60, U1.8
/ABUS_D8_3V: CON1.E13, U1.41
/ABUS_D9: CN1.A61, U1.9
/ABUS_D9_3V: CON1.E11, U1.40
/ABUS_D10: CN1.A62, U1.11
/ABUS_D10_3V: CON1.E7, U1.38
/ABUS_D11: CN1.A63, U1.12
/ABUS_D11_3V: CON1.E5, U1.37
/ABUS_D12: CN1.B63, U1.23
/ABUS_D12_3V: CON1.E24, U1.26
/ABUS_D13: CN1.B62, U1.22
/ABUS_D13_3V: CON1.E20, U1.27
/ABUS_D14: CN1.B61, U1.20
/ABUS_D14_3V: CON1.E18, U1.29
/ABUS_D15: CN1.B60, U1.19
/ABUS_D15_3V: CON1.E14, U1.30
/ABUS_DATA_DIR: CON1.D4, U1.1, U1.24
/ABUS_IRQ: CN1.B53, U5.4
/ABUS_IRQ_3V: CON1.E31, U5.3
/ABUS_IRQ_DIR: CON1.E29, U5.5
/ABUS_RD: CN1.B47, U3.20
/ABUS_RD_3V: CON1.E32, U3.29
/ABUS_WAIT: CN1.B52, U4.4
/ABUS_WAIT_3V: CON1.E37, U4.3
/ABUS_WAIT_DIR: CON1.E35, U4.5
/ABUS_WR0: CN1.A49, U6.2
/ABUS_WR0_3V: CON1.F24, U6.47
/ABUS_WR1: CN1.B49, U3.23
/ABUS_WR1_3V: CON1.E38, U3.26
/COPRO_RST: CN1.A66, U9.5
/COPRO_RST_3V: CON1.C36, U9.44
/CRTG0: CN1.A30, U8.17
/CRTG0_3V: CON1.D32, U8.4
/CRTG1: CN1.B30, U8.16
/CRTG1_3V: CON1.D30, U8.5
/DBCK: CN1.B5, U9.14
/DBCK_3V: CON1.C30, U9.35
/DLRCLK: CN1.B6, U9.16
/DLRCLK_3V: CON1.C29, U9.33
/DOTCLK: CN1.A28, U9.2
/DOTCLK_3V: CON1.C38, U9.47
/DSD: CN1.B4, U9.13
/DSD_3V: CON1.C31, U9.36
/EXBG0: CN1.A9, U7.17
/EXBG0_3V: CON1.D29, U7.32
/EXBG1: CN1.B9, U2.3
/EXBG1_3V: CON1.C20, U2.46
/EXBG2: CN1.A10, U7.16
/EXBG2_3V: CON1.D25, U7.33
/EXBG3: CN1.B10, U2.5
/EXBG3_3V: CON1.C19, U2.44
/EXBG4: CN1.A11, U7.14
/EXBG4_3V: CON1.D26, U7.35
/EXBG5: CN1.B11, U2.6
/EXBG5_3V: CON1.C18, U2.43
/EXBG6: CN1.A12, U7.13
/EXBG6_3V: CON1.D23, U7.36
/EXBG7: CN1.B12, U2.8
/EXBG7_3V: CON1.C17, U2.41
/EXBG8: CN1.A14, U7.12
/EXBG8_3V: CON1.D24, U7.37
/EXBG9: CN1.B14, U2.9
/EXBG9_3V: CON1.C14, U2.40
/EXBG10: CN1.A15, U7.11
/EXBG10_3V: CON1.D19, U7.38
/EXBG11: CN1.B15, U2.11
/EXBG11_3V: CON1.C13, U2.38
/EXBG12: CN1.A16, U7.9
/EXBG12_3V: CON1.D20, U7.40
/EXBG13: CN1.B16, U2.12
/EXBG13_3V: CON1.C12, U2.37
/EXBG14: CN1.A17, U7.8
/EXBG14_3V: CON1.D17, U7.41
/EXBG15: CN1.B17, U2.13
/EXBG15_3V: CON1.C11, U2.36
/EXBG16: CN1.A19, U7.6
/EXBG16_3V: CON1.D18, U7.43
/EXBG17: CN1.B19, U2.14
/EXBG17_3V: CON1.C8, U2.35
/EXBG18: CN1.A20, U7.5
/EXBG18_3V: CON1.D13, U7.44
/EXBG19: CN1.B20, U2.16
/EXBG19_3V: CON1.C7, U2.33
/EXBG20: CN1.A21, U7.3
/EXBG20_3V: CON1.D14, U7.46
/EXBG21: CN1.B21, U2.17
/EXBG21_3V: CON1.C6, U2.32
/EXBG22: CN1.A22, U7.2
/EXBG22_3V: CON1.D11, U7.47
/EXBG23: CN1.B22, U2.19
/EXBG23_3V: CON1.C5, U2.30
/EXLAT: CN1.A25, U2.20
/EXLAT_3V: CON1.C4, U2.29
/EXON: CN1.A24, U8.18
/EXON_3V: CON1.D36, U8.3
/EXSL: CN1.B25, U9.23
/EXSL_3V: CON1.C24, U9.26
/EXSYNC: CN1.B28, U2.22
/EXSYNC_3V: CON1.D6, U2.27
/HSYNC: CN1.A26, U9.11
/HSYNC_3V: CON1.C35, U9.38
/IBCK: CN1.A5, U7.22
/IBCK_3V: CON1.D35, U7.27
/ILRCK: CN1.A6, U7.20
/ILRCK_3V: CON1.D31, U7.29
/ISD: CN1.A4, U7.23
/ISD_3V: CON1.D37, U7.26
/LCD_DC: U12.20, U13.5
/LCD_DC_1_8V: CON1.B32, U12.3
/LCD_LED: U11.12, U13.8
/LCD_LED_1_8V: CON1.B35, U11.9
/LCD_RESET: U12.16, U13.4
/LCD_RESET_1_8V: CON1.B30, U12.4
/MCLK: CN1.B66, U9.3
/MCLK_3V: CON1.C37, U9.46
/MPEGON: CN1.B24, U8.20
/MPEGON_3V: CON1.D38, U8.1
/RESET: CN1.A3, U9.17
/RESET_3V: CON1.C26, U9.32
/SCSPCLK: CN1.A7, U9.19
/SCSPCLK_3V: CON1.C25, U9.30
/SD_CD/DAT3: CON2.1, R2.2, U11.18
/SD_CD/DAT3_1_8V: CON1.B13, U11.3
/SD_CLK: CON2.5, U11.16
/SD_CLK_1_8V: CON1.B5, U11.5
/SD_CMD: CON2.2, R3.2, U11.17
/SD_CMD_1_8V: CON1.B7, U11.4
/SD_DAT0: CON2.7, R4.2, U11.15
/SD_DAT0_1_8V: CON1.B8, U11.6
/SD_DAT1: CON2.8, R5.2, U11.14
/SD_DAT1_1_8V: CON1.B6, U11.7
/SD_DAT2: CON2.9, R1.2, U11.20
/SD_DAT2_1_8V: CON1.B11, U11.1
/SD_WP: CON2.10, U11.13
/SD_WP_1_8V: CON1.B14, U11.8
/SPI_CS0: U12.15, U13.3
/SPI_CS0_1_8V: CON1.B26, U12.6
/SPI_CS1_1_8V: CON1.B24, U12.8
/SPI_CS2_1_8V: CON1.B29, U12.5
/SPI_MISO: U12.14, U13.9
/SPI_MISO_1_8V: CON1.B25, U12.7
/SPI_MOSI: U12.18, U13.6
/SPI_MOSI_1_8V: CON1.B31, U12.1
/SPI_SCK: U12.12, U13.7
/SPI_SCK_1_8V: CON1.B23, U12.9
/SSEL: CN1.B3, U2.2
/SSEL_3V: CON1.C23, U2.47
/VSYNC: CN1.B26, U9.12
/VSYNC_3V: CON1.C32, U9.37
GND: C1.2, C2.2, C3.2, C4.2, C5.2, C6.2, C7.2, C8.2, C9.2, C10.2, C11.2, C12.2, C13.2, C14.2, C15.2, C16.2, C17.2, C18.2, C19.2, C20.2, C21.2, C22.2, C23.2, C24.2, C25.2, C26.2, C27.2, C28.2, C29.2, C30.2, C31.2, C32.2, C33.2, C34.2, C35.2, C36.2, C37.2, C38.2, CN1.A8, CN1.A13, CN1.A18, CN1.A23, CN1.A29, CN1.A36, CN1.A41, CN1.A46, CN1.A54, CN1.A59, CN1.A64, CN1.A65, CN1.B7, CN1.B8, CN1.B13, CN1.B18, CN1.B23, CN1.B29, CN1.B36, CN1.B41, CN1.B46, CN1.B54, CN1.B59, CN1.B64, CN1.B65, CON1.A5, CON1.A6, CON1.A9, CON1.A10, CON1.A20, CON1.A27, CON1.A28, CON1.B9, CON1.B10, CON1.B15, CON1.B16, CON1.B21, CON1.B22, CON1.B27, CON1.B28, CON1.B33, CON1.B34, CON1.C9, CON1.C10, CON1.C15, CON1.C16, CON1.C21, CON1.C22, CON1.C27, CON1.C28, CON1.C33, CON1.C34, CON1.D9, CON1.D10, CON1.D15, CON1.D16, CON1.D21, CON1.D22, CON1.D27, CON1.D28, CON1.D33, CON1.D34, CON1.E9, CON1.E10, CON1.E15, CON1.E16, CON1.E21, CON1.E22, CON1.E27, CON1.E28, CON1.E33, CON1.E34, CON1.F9, CON1.F10, CON1.F15, CON1.F16, CON1.F21, CON1.F22, CON1.F27, CON1.F28, CON1.F33, CON1.F34, CON2.3, CON2.6, CON2.12, CON2.13, U1.4, U1.10, U1.15, U1.21, U1.25, U1.28, U1.34, U1.39, U1.45, U1.48, U2.4, U2.10, U2.15, U2.21, U2.25, U2.28, U2.34, U2.39, U2.45, U2.48, U3.1, U3.4, U3.10, U3.15, U3.21, U3.24, U3.25, U3.28, U3.34, U3.39, U3.45, U3.48, U4.2, U5.2, U6.1, U6.4, U6.10, U6.15, U6.21, U6.24, U6.25, U6.28, U6.34, U6.39, U6.45, U6.48, U7.4, U7.10, U7.15, U7.21, U7.25, U7.28, U7.34, U7.39, U7.45, U7.48, U9.1, U9.4, U9.10, U9.15, U9.21, U9.24, U9.25, U9.28, U9.34, U9.39, U9.45, U9.48, U10.1, U10.2, U10.3, U10.4, U13.2
unnamed: CON1.C39, R8.2, U10.6
unnamed: CON1.C40, R7.2, U10.5
unnamed: R6.2, U10.7

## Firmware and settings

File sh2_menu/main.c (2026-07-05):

#include <yaul.h>

#include <stdio.h>
#include <stdlib.h>
#include <stdbool.h>

#include "font.h"
#include "input.h"
#include "video.h"
#include "control.h"
#include "video_vdp2.h"

#define MENU_VERSION_MAJOR 1
#define MENU_VERSION_MINOR 1

int global_frame_count = 0;

static void suite_vblank_out_handler(void *work __unused)
{
    global_frame_count++;
    
    if (0==video_is_inited())
        return;
    
    smpc_peripheral_intback_issue();
}

uint32_t NextRandom(uint32_t prev) {
	//return (prev+0x10001);
	if (((prev & 0x80000000) / 0x80000000) ^ ((prev & 0x40000000) / 0x40000000)
			^ ((prev & 0x10) / 0x10) ^ ((prev & 0x8) / 0x8))
		return (prev & 0x7FFFFFFF) * 2 + 1;
	else
		return (prev & 0x7FFFFFFF) * 2;
}

void get_version_string(char * buf) {
	uint16_t* pWascaRegs = (uint16_t*)0x23FFFFE0;
	sprintf(buf, "v.%d.%d RISC-V %d.%d HW %d.%d",MENU_VERSION_MAJOR,MENU_VERSION_MINOR,
		pWascaRegs[12]/256,pWascaRegs[12]%256,
		pWascaRegs[11]/256,pWascaRegs[11]%256);
}

void redraw_menu (int current_item) {
	char string_buf[128];
	int x = 20;
	int y = 10;
	uint8_t* pAdvertiseList = (uint8_t*)0x23000000;

	DrawString("wasca menu", x+40, y, FONT_WHITE);
	get_version_string(string_buf);
	DrawString(string_buf, x+40+12*_fw, y, FONT_WHITE);y+=_fh;
	y+=_fh;
	int offset = 1;
	int item = 0;
	while ((pAdvertiseList[offset] != 0) &&(item < 20)) {
		sprintf(string_buf,"%i. %s", pAdvertiseList[offset],&(pAdvertiseList[offset+1]));
		DrawString(string_buf, x, y, (item == current_item) ? FONT_GREEN : FONT_WHITE);y+=_fh;
		item++; 
		offset+=64;
	}
	
	y+=_fh;
	DrawString("A : Select and reboot", x+10, y, FONT_WHITE);y+=_fh;
	DrawString("B : Multiplayer", x+10, y, FONT_WHITE);y+=_fh;
	DrawString("C : Select and Multiplayer", x+10, y, FONT_WHITE);y+=_fh;
}

int main(void)
{
	char string_buf[128];
	uint16_t counter;

	video_screen_mode_t screenMode =
	{
		.scanmode = VIDEO_SCANMODE_240P,
		.x_res = VIDEO_X_RESOLUTION_320,
		.y_res = VDP2_TVMD_VERT_240,
		.x_res_doubled = false,
		.colorsystem = VDP2_TVMD_TV_STANDARD_NTSC,
	};

	video_init(screenMode,false);
	//video_vdp2_set_cycle_patterns_cpu();
	video_vdp2_set_cycle_patterns_nbg(screenMode);

	video_vdp2_clear_palette(0);
	SetFontPalette();

	//detect color system
	screenMode.colorsystem = vdp2_tvmd_tv_standard_get();

	//measure frame clock
	volatile int frame_counter=0;
	while (vdp2_tvmd_vblank_out())
		;
	while (vdp2_tvmd_vblank_in())
		frame_counter++;
	while (vdp2_tvmd_vblank_out())
		frame_counter++;

	//register vblank handler
	vdp_sync_vblank_out_set(suite_vblank_out_handler, NULL);
	
	//calculating advertising list size
	uint8_t* pAdvertiseList = (uint8_t*)0x23000000;

	int offset = 1;
	int list_size = 0;
	while ((pAdvertiseList[offset] != 0) &&(list_size < 24)) {
		list_size++; 
		offset+=64;
	}
	
	int current_item = 0;
	int preparing = 0;
	int go_reboot = 0;
	int go_multiplayer = 0;
	uint16_t* pWascaRegs = (uint16_t*)0x23FFFFE0;
	
	while(true)
	{
		vdp2_tvmd_vblank_out_wait();
		smpc_peripheral_process();
		get_digital_keypress_anywhere(&controller);
		
		if(controller.pressed.button.up) {
			wait_for_key_unpress();
			current_item--;
			if (current_item < 0)
				current_item = list_size - 1;				
		}
		if(controller.pressed.button.down) {
			wait_for_key_unpress();
			current_item++;
			if (current_item >= list_size)
				current_item = 0;				
		}
		if ((preparing == 0) && (controller.pressed.button.a)) {
			wait_for_key_unpress();
			pWascaRegs[10] = current_item+1;
			ClearText(10,(list_size+4)*_fh,280,_fh*3);
			preparing = 1;
			go_reboot = 1;
		}
		if ((preparing == 0) && (controller.pressed.button.b)) {
			wait_for_key_unpress();
			preparing = 2;
			go_multiplayer = 1;
		}
		if ((preparing == 0) && (controller.pressed.button.c)) {
			wait_for_key_unpress();
			pWascaRegs[10] = current_item+1;
			ClearText(10,(list_size+4)*_fh,280,_fh*3);
			preparing = 1;
			go_multiplayer = 1;
		}

		if (preparing == 1) {
			counter = pWascaRegs[8];
			ClearText(70+strlen("Loading: ")*_fw,(list_size+5)*_fh,3*_fw,_fh);
			sprintf(string_buf,"Loading: %3d percents     ",counter);
			DrawString(string_buf, 70, (list_size+5)*_fh, FONT_WHITE);
			if (counter == 100)
				preparing = 2;
		}

		if (preparing == 2) {
			ClearText(70+strlen("Loading: ")*_fw,(list_size+5)*_fh,15*_fw,_fh);
			sprintf(string_buf,"Loading: complete");
			DrawString(string_buf, 70, (list_size+5)*_fh, FONT_WHITE);

			preparing = 0;
			if (go_reboot)
				bios_execute();
			else if (go_multiplayer)
				bios_cd_player_execute();
		}

		if (preparing == 0)
			redraw_menu(current_item);

		vdp2_sync();
		vdp2_sync_wait();
	}
}

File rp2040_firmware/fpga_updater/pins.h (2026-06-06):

#define QSPI_CLK_PIN 3
#define QSPI_CS_PIN 7
#define QSPI_D0_PIN 5
#define QSPI_D1_PIN 9
#define QSPI_D2_PIN 11
#define QSPI_D3_PIN 1
#define PROGRAMN_PIN 18

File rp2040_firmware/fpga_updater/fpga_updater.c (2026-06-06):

/*
 * The MIT License (MIT)
 *
 * Copyright (c) 2019 Ha Thach (tinyusb.org)
 *
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
 */

#include "bsp/board_api.h"
#include "tusb.h"
#include "pins.h"
#include <stdarg.h>
#include "pico/stdlib.h"

//--------------------------------------------------------------------+
// MACRO CONSTANT TYPEDEF PROTYPES
//--------------------------------------------------------------------+

/* Blink pattern
 * - 250 ms  : device not mounted
 * - 1000 ms : device mounted
 * - 2500 ms : device is suspended
 */
enum {
  BLINK_NOT_MOUNTED = 250,
  BLINK_MOUNTED = 1000,
  BLINK_SUSPENDED = 2500,
};

static uint32_t blink_interval_ms = BLINK_NOT_MOUNTED;

void led_blinking_task(void);
void cdc_task(void);
int log_printf(const char *fmt, ...);

/*------------- MAIN -------------*/
int main(void) {
  board_init();

  // init device stack on configured roothub port
  tusb_rhport_init_t dev_init = {
    .role = TUSB_ROLE_DEVICE,
    .speed = TUSB_SPEED_AUTO
  };
  tusb_init(BOARD_TUD_RHPORT, &dev_init);

  gpio_init(QSPI_CLK_PIN);
  gpio_init(QSPI_CS_PIN);
  gpio_init(QSPI_D0_PIN);
  gpio_init(QSPI_D1_PIN);
  gpio_init(QSPI_D2_PIN);
  gpio_init(QSPI_D3_PIN);
  gpio_init(PROGRAMN_PIN);
  gpio_set_dir(QSPI_CLK_PIN, GPIO_IN);
  gpio_set_dir(QSPI_CS_PIN, GPIO_IN);
  gpio_set_dir(QSPI_D0_PIN, GPIO_IN);
  gpio_set_dir(QSPI_D1_PIN, GPIO_IN);
  gpio_set_dir(QSPI_D2_PIN, GPIO_IN);
  gpio_set_dir(QSPI_D3_PIN, GPIO_IN);
  gpio_set_dir(PROGRAMN_PIN, GPIO_OUT);
  gpio_put(QSPI_CLK_PIN,0);
  gpio_put(QSPI_CS_PIN,0);
  gpio_put(QSPI_D0_PIN,0);
  gpio_put(PROGRAMN_PIN,1);

  if (board_init_after_tusb) {
    board_init_after_tusb();
  }

  while (1) {
    tud_task(); // tinyusb device task
    //led_blinking_task();

    cdc_task();
  }
}

//--------------------------------------------------------------------+
// Device callbacks
//--------------------------------------------------------------------+

// Invoked when device is mounted
void tud_mount_cb(void) {
  blink_interval_ms = BLINK_MOUNTED;
}

// Invoked when device is unmounted
void tud_umount_cb(void) {
  blink_interval_ms = BLINK_NOT_MOUNTED;
}

// Invoked when usb bus is suspended
// remote_wakeup_en : if host allow us  to perform remote wakeup
// Within 7ms, device must draw an average of current less than 2.5 mA from bus
void tud_suspend_cb(bool remote_wakeup_en) {
  (void) remote_wakeup_en;
  blink_interval_ms = BLINK_SUSPENDED;
}

// Invoked when usb bus is resumed
void tud_resume_cb(void) {
  blink_interval_ms = tud_mounted() ? BLINK_MOUNTED : BLINK_NOT_MOUNTED;
}


//--------------------------------------------------------------------+
// USB CDC
//--------------------------------------------------------------------+
void cdc_task(void) {
  // connected() check for DTR bit
  // Most but not all terminal client set this when making connection
  // if ( tud_cdc_connected() )
  {
    // connected and there are data available
    if (tud_cdc_available()) {
      // read data
      char buf[64];
      //uint32_t count = tud_cdc_read(buf, sizeof(buf));
      sprintf(buf,"Hello!!!!!\r\n");
      uint32_t count  = strlen(buf);
      (void) count;

      // Echo back
      // Note: Skip echo by commenting out write() and write_flush()
      // for throughput test e.g
      //    $ dd if=/dev/zero of=/dev/ttyACM0 count=10000
      //tud_cdc_write(buf, count);
      //tud_cdc_write_flush();
    }
  }
}

// Invoked when cdc when line state changed e.g connected/disconnected
void tud_cdc_line_state_cb(uint8_t itf, bool dtr, bool rts) {
  (void) itf;
  (void) rts;

  // TODO set some indicator
  if (dtr) {
    // Terminal connected
  } else {
    // Terminal disconnected
  }
}

// Invoked when CDC interface received data from host
void tud_cdc_rx_cb(uint8_t itf) {
  (void) itf;
}

//--------------------------------------------------------------------+
// BLINKING TASK
//--------------------------------------------------------------------+
void led_blinking_task(void) {
  static uint32_t start_ms = 0;
  static bool led_state = false;

  // Blink every interval ms
  if (board_millis() - start_ms < blink_interval_ms) return; // not enough time
  start_ms += blink_interval_ms;

  board_led_write(led_state);
  led_state = 1 - led_state; // toggle

}

char sprintf_buffer[256];
int
log_printf(const char *fmt, ...)
{
	int ret;
	va_list va;
	va_start(va, fmt);
	ret = vsnprintf(sprintf_buffer, 512, fmt, va);
	va_end(va);

  if (ret) {
    tud_cdc_write(sprintf_buffer, ret);
    tud_cdc_write_flush();
  }

	return ret;
}

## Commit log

2015-04-29 Pre-route schematic. Kinda finished. Will change after route.
    [wasca.sch]
2015-05-06 PCB preparement
    [wasca.sch]
2015-05-06 PCB routing started
    [wasca.kicad_pcb, wasca.sch]
2015-05-13 Route in progress
    [contour.kicad_pcb, wasca.dsn, wasca.kicad_pcb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]
2015-05-21 Routed at last.
    [wasca.kicad_pcb, wasca.sch]
2015-06-03 SCSP 22.57 MHz clock is used instead of 27..29 MHz MCLK2
    [wasca.kicad_pcb, wasca.sch]
2015-06-03 FPGA firmware added (preliminary)
    [wasca.csv]
2015-06-04 Silkscreen fix
    [wasca.kicad_pcb]
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2015-06-05 Board cleanup, intersected parts fix (thanks cafealpha2), more ground vias.
    [wasca.kicad_pcb]
2015-06-05 Gerbers and drill files added.
    [wasca-B_Cu.gbl, wasca-B_Mask.gbs, wasca-B_SilkS.gbo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]
2015-06-05 Silkscreen cleanup
    [wasca.kicad_pcb, wasca.sch]
2015-06-06 Board name and version added
    [wasca-B_Cu.gbl, wasca-B_Mask.gbs, wasca-B_SilkS.gbo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]
2015-06-23 A-bus to avalon in progress
    [wasca.csv]
2015-07-14 A-Bus interface done, not tested
    [wasca.csv]
2015-07-28 Power memory simulation (volatile)
    [wasca.csv]
2015-10-07 Major board fixes
    [wasca.kicad_pcb, wasca.sch]
2015-10-07 Board 1.1 released
    [wasca-B_Cu.gbl, wasca-B_Mask.gbs, wasca-B_SilkS.gbo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]
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2016-05-27 Wasca evolution as a snickerdoodle baseboard, see https://github.com/krtkl/snickerdoodle-manual
    [wasca_v2.kicad_pcb, wasca_v2.sch]
2016-05-30 Schematic update, SPI display added
    [wasca_v2.kicad_pcb, wasca_v2.sch]
2016-05-31 Pin swapping (incomplete)
    [wasca_v2.kicad_pcb, wasca_v2.sch]
2016-06-03 Almost routed
    [wasca_v2.kicad_pcb, wasca_v2.sch]
2016-06-05 Route done
    [wasca_v2-B.Mask.gbs, wasca_v2-B.SilkS.gbo, wasca_v2-Back.gbl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]
2016-07-13 Board v1.2 related stuff (preliminary)
    - Cartridge schematics and routing 99 % done
    - USB mezzanine board 99% done
    - MAX10 firmware stub from v1.1 sources
    [contour.kicad_pcb, usbcart.dsn, usbcart.kicad_pcb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]
2016-07-14 Minor changes to boards
    - Added chip orientation information for 3V3 buffers and MAX10
    footprints
    - Added gerber files
    [usbcart-B.Mask.gbs, usbcart-B.SilkS.gbo, usbcart-Back.gbl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]
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2020-08-13 Migrating from 15.0 to 15.1, debug signaltap updated, .gitignore added
    [wasca_signaltap.stp]
2020-08-20 Bridge core debugging in Qsys. Avalon almost works, some bus width issues are not yet fixed
    [wasca_signaltap.stp]
2020-08-28 RAM 1M mirroring fixed, now it doesn't mirror entire bus, but only its region. Wascaloader updated, pseudo support added. I2S bus switched back to CD block (was switched to wasca accidentally).
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2020-09-20 Power memory sync fix
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2020-09-28 Embedding buffered spi, some inferring gone wrong
2020-09-28 Changing inferred BRAM to generated BRAM in Buffered spi core. Adding to qsys (as a replace for STM32 spi)
2020-10-03 SPI core works correctly in transmit mode (receive not tested yet). A simple test is added at the start of the main.
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2020-10-09 Fixing data init size for power memory.
2020-10-13 Mapper register set works. Fixed incorrect disable value for waitrequest and interrupt
2020-11-09 Moving V2 to the "obsolete" folder to mark its obsolescence
    [wasca_v2-B.Mask.gbs, wasca_v2-B.SilkS.gbo, wasca_v2-Back.gbl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]
2020-12-06 Migration to 18.1. Pin remap and HDL change according to non-multiplexed design.
    [wasca.csv]
2020-12-06 Board 1.4 (not finished yet)
    [wasca.dsn, wasca.kicad_pcb, wasca.sch]
2020-12-07 Obsolete schematic parts update
    [wasca.kicad_pcb, wasca.sch]
2020-12-07 Reroute of swapped pins
    [wasca.kicad_pcb]
2020-12-08 LEDs update, STM32 debug UART added to spare pin header.
    [wasca.kicad_pcb, wasca.sch]
2020-12-10 Further routing
    [wasca.kicad_pcb]
2020-12-10 Routing done
    [wasca.kicad_pcb, wasca.sch]
2020-12-10 STM32 pinout update
    [wasca.sch]
2020-12-12 Finalizing stuff for 1.4: cleanup, silkscreen, comments etc.
    [wasca.kicad_pcb, wasca.sch]
2020-12-13 Changing FPGA part to 10M08SCE144C8G. BOM recompilation.
    [wasca.kicad_pcb, wasca.sch]
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2020-12-19 SSEL pin duplicated to STM32
    [wasca.kicad_pcb, wasca.sch]
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2021-01-21 Added buffered log output to STM32 (which shall then send the logs to PC via USB) Can now select between log output to STM32 or UART Small changes regarding boot ROM selection
    [wasca.csv]
2021-01-30 PCB production preparement
    [wasca-B_Cu.gbl, wasca-B_Mask.gbs, wasca-B_SilkS.gbo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]
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2021-01-31 Initial addition of STM32 firmware ... which doesn't features everything and isn't tested for real.
    [main.c, wasca_link_spi.h]
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2021-01-31 Change PPL input clock frequency to 8 MHz (modified clock setup on STM32 side, but forgot to do this here ... stupid bug as usual)
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2021-02-05 Removing v12 folder before merging (will be re-added as a branch to hitomi2500/wasca after merging)
    [contour.kicad_pcb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]
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2021-02-10 Fix last character missing when sending log message through UART
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2021-02-11 Add settings files for OpenOCD
    [stlink-v2.cfg, stm32f4x.cfg]
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2021-02-12 Avoid a warning when latest ARM compiler is used
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2021-02-13 A bit smarter data integrity check during SPI transfer (but still not working well)
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2021-02-25 SPI pins mapped correctly in .qsf file. Quartus design regeneration.
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2021-06-19 Fixed SPI communication test feature * Tested on DE10-lite board, but not on 10M08SC architecture * It is currently not called, but this will be done when adding interaction with SH-2
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2021-07-12 Board 1.5 update (unchecked)
    [wasca.kicad_pcb, wasca.sch]
2021-07-13 Board 1.5 , STM-to-MAX JTAG detached from UART
    [wasca.kicad_pcb, wasca.sch]
2021-07-15 Added logging from MAX 10 via SPI to SD card Fixed several bugs
    [main.c, wasca_link_spi.h]
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2021-07-22 Fixed stupid bug when accessing 0.5MB backup memory file (I just started review on STM32 side ... more fixes may follow)
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2021-08-01 Log location in source when a problem happened on STM32 side
    [main.c]
2021-08-01 Throw error message when SPI communication failed on STM32 side Everything works well on my DE10-lite board, but not on my Wasca-compatible board. Errors don't happen on the former because it uses ha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
2021-08-03 Periodically change MAX 10 LED beat frequency in order to be sure that NIOS execution didn't froze. (Also features some fixes regarding mode initial setup)
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2021-08-11 Added SPI clock divider setting from ini file Fixed MODE register setting from SH-2 Use settings from SD card (until now it was tweaked to use only default settings)
    [wasca_link_spi.h]
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2022-01-12 SODIMM based board (preliminary work)
    [wasca.kicad_pcb, wasca.sch]
2022-01-17 SODIMM based board (schematics & routing in progress)
    [wasca.kicad_pcb, wasca.sch]
2022-01-27 Schematics & routing in progress
    [wasca.kicad_pcb, wasca.sch]
2022-03-21 Migration to Kicad 6
    [wasca.kicad_pcb, wasca.kicad_sch]
2022-03-26 Post-migration cleanup, routing
    [wasca.kicad_pcb, wasca.kicad_sch]
2022-03-26 Further cleanup
    [wasca.kicad_pcb, wasca.kicad_sch]
2022-03-29 USB removed. Second SDRAM added. Reroute (incomplete)
    [wasca.kicad_pcb, wasca.kicad_sch]
2022-03-30 Reroute complete, cleanup pending.
    [wasca.kicad_pcb, wasca.kicad_sch]
2022-04-01 Full SD card
    [wasca.kicad_sch]
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2022-04-13 "Endorsed by SHIRO!" logo
    [wasca.kicad_pcb, wasca.kicad_sch]
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2023-09-17 Fixing soldermask in SODIMM connector
2023-09-17 Migrating to Kicad 7
    [wasca.kicad_pcb, wasca.kicad_sch]
2023-09-17 Adding HyperRAM as an alternative for SDRAM
    [wasca.kicad_pcb, wasca.kicad_sch]
2023-09-18 Gerbers update, version 1.7
    [wasca-B_Mask.gbs, wasca-B_SilkS.gbo, wasca-B_Silkscreen.gbo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]
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2026-04-03 A-bus fixes, current clocks are 125/47/25 MHz
    [sdram_bridge.v]
2026-04-08 Second SDRAM (timings fail atm)
    [mt48lc16m16a2.v, sdram_bridge.v]
2026-04-08 SDRAM2 mapping fix, typos
    [sdram_bridge.v]
2026-04-10 Timing for SDRAM1, SDRAM2 not working yet
    [sdram_bridge.v]
2026-04-22 WR0 and WR1 fix
    [sdram_bridge.v]
2026-04-22 CS0 and CS1 fix
    [sdram_bridge.v]
2026-04-24 SDRAM1 works for read and write from Abus, SDRAm2 still unstable
    [sdram_bridge.v]
2026-05-03 CS1 rework, using ESP32 lines for debug
    [sdram_bridge.v]
2026-05-04 CS0 works without errors! CS1 fails miserably atm.
    [sdram_bridge.v]
2026-05-04 Both CS0 and CS1 work without errors with delay >= 2
    [sdram_bridge.v]
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2026-05-09 Transaction dir latching fix. Prelimirnary LED support.
    [sdram_bridge.v]
2026-05-10 Migrating to Kicad 10
    [wasca.kicad_pcb, wasca.kicad_sch]
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2026-05-14 Sweeping old stuff under the rug
    [contour.kicad_pcb, stlink-v2.cfg, stm32f4x.cfg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]
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2026-05-21 Moving RP2040 to front to simplify 2-stage assembly (front at fab, back manually).
    [wasca.kicad_pcb, wasca.kicad_sch]
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2026-06-08 NPTH update on board
    [wasca.kicad_pcb]
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2026-06-11 Oscillator update for easier handsoldering
    [wasca.kicad_pcb, wasca.kicad_sch]
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2026-06-24 Up to 18 items in menu, progress drawing fix
    [firmware.c, main.c]
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2026-08-16 Reducing prototype board clock to 137MHz (does not work)
    [sdram_bridge.v]
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

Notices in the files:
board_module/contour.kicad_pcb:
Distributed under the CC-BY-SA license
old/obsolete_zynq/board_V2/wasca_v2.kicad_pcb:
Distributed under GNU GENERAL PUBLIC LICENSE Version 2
